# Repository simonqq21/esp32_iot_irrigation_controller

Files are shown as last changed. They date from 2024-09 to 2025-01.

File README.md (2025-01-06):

# ESP32 WiFi-Enabled Relay

# Introduction
The ESP32 WiFi-enabled relay is a proof-of-concept project that allows the user to control multiple AC sockets connected to relays by either a physical button, web interface on a browser, repeating daily schedule, countdown timer, or with other programming languages from a server computer via a websocket connection.  

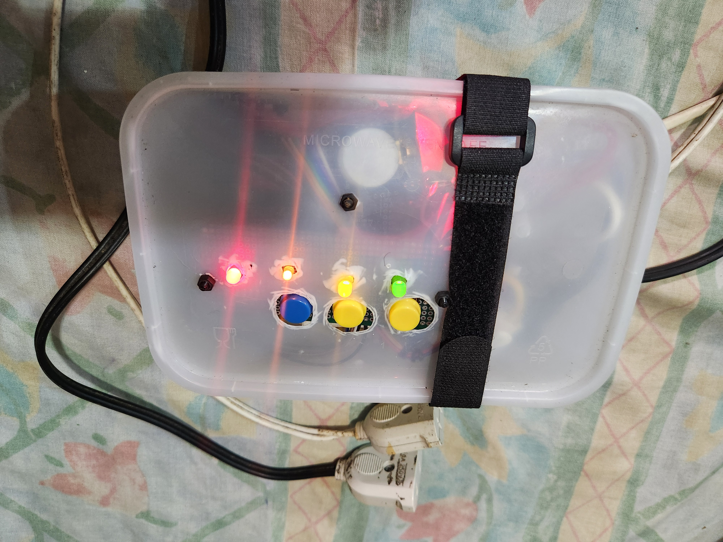
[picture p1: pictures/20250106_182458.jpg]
ESP32 WiFi-Enabled Relay picture 1

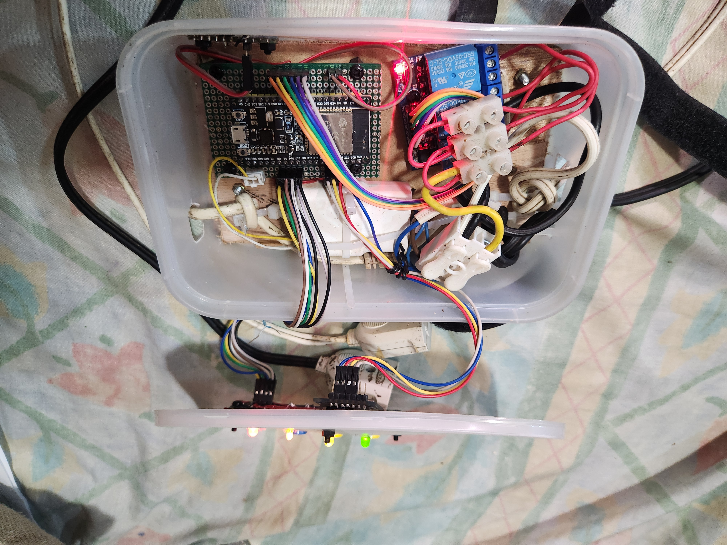
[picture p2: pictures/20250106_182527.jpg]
ESP32 WiFi-Enabled Relay picture 2

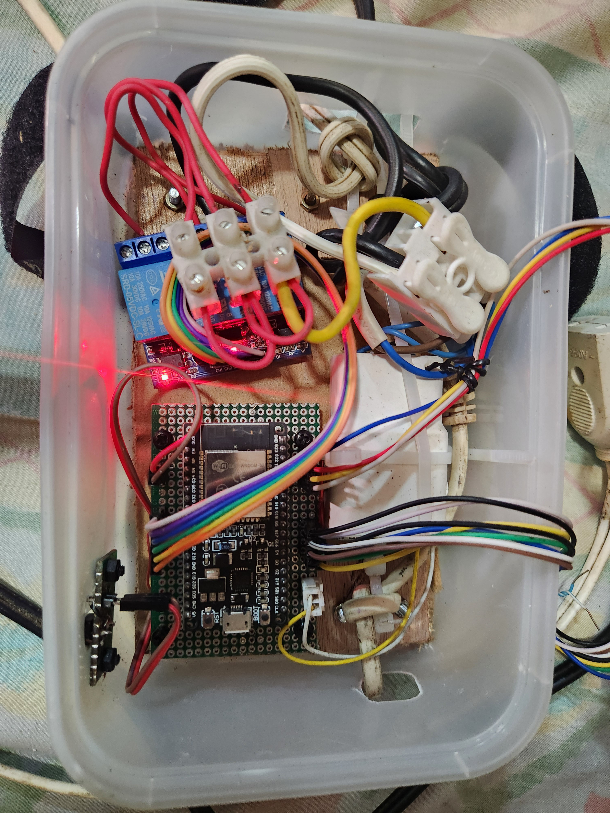
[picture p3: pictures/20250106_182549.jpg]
ESP32 WiFi-Enabled Relay picture 3


# Features
- Runs on an **ESP32**
- Three relays, but can be configured with more or less relays.
- Each relay functions independently of each other.
- Each relay has a **physical pushbutton** for **manual control** and **cycling through operating modes**, and a **status LED** to indicate its **operating mode** (either manual, daily timer, countdown timer, or disabled) and **current state** (either closed or open).
- The ESP32 can be **configured to connect to any WiFi hotspot** by configuring it from the browser of any mobile or desktop device, or **create its own hotspot** for standalone use.
- **Physical WiFi reset button** to reset the WiFi connection to factory defaults.
- **Web interface** accessible through the browser of any mobile or desktop device. 
- The web interface running on the browser communicates to the ESP32 via a **websocket connection**.
- Time is kept via a **real time clock (RTC)**, and can either be **set manually** or **synced automatically to network time protocol (NTP)**.
- All configuration is persistent and is saved to the flash of the ESP32. 

# Hardware 
## Hardware components
The ESP32 WiFi-enabled relay has the following hardware components:
- ESP32 
- 3.3V/5V relay module x3
- DS1307 RTC module
- LED x3 for relay status LEDs
- Momentary pushbutton x3 for relay control
- LED x1 for main status LED
- Momentary pushbutton x1 for WiFi reset pushbutton
- AC to 5V power supply module 
## Circuit Diagram
- **ESP32 PCB Circuit Diagram**

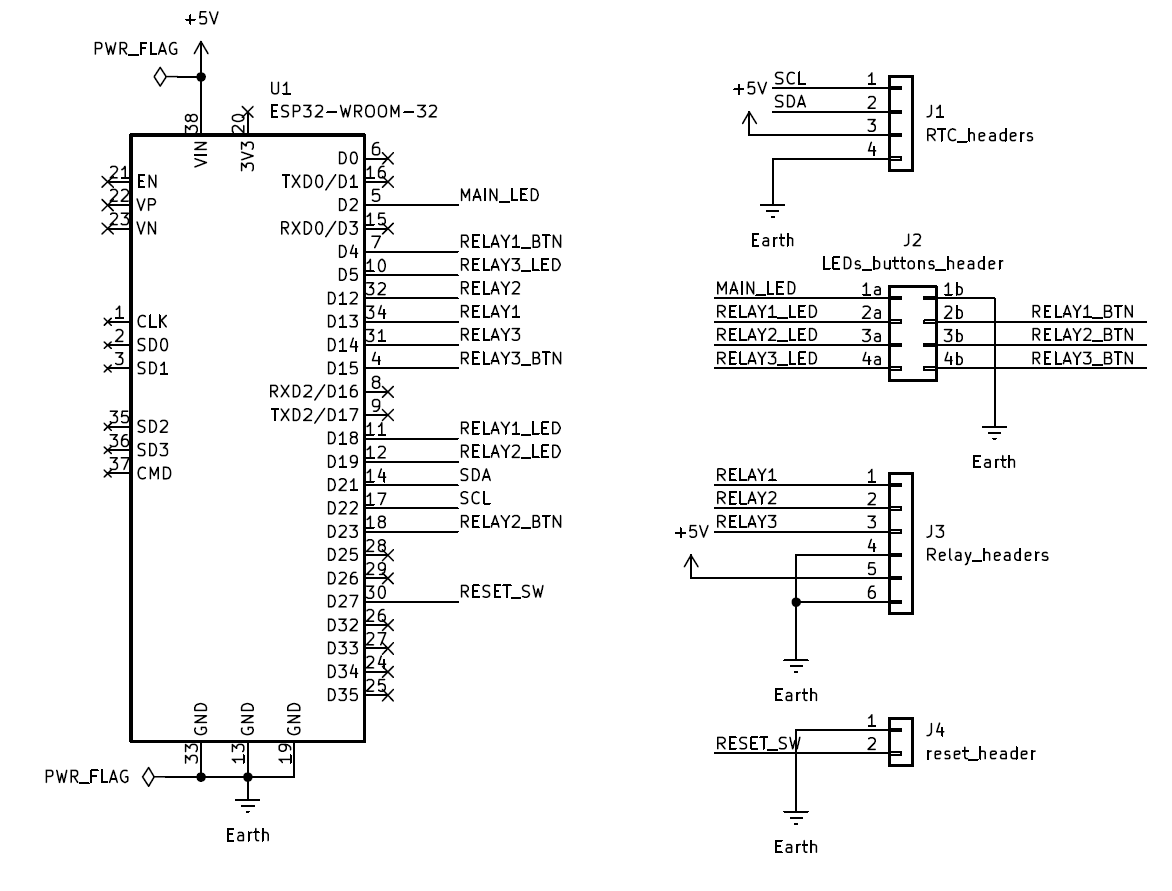
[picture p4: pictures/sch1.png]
ESP32 PCB Diagram


- **LEDs and Pushbuttons PCB Circuit Diagram**

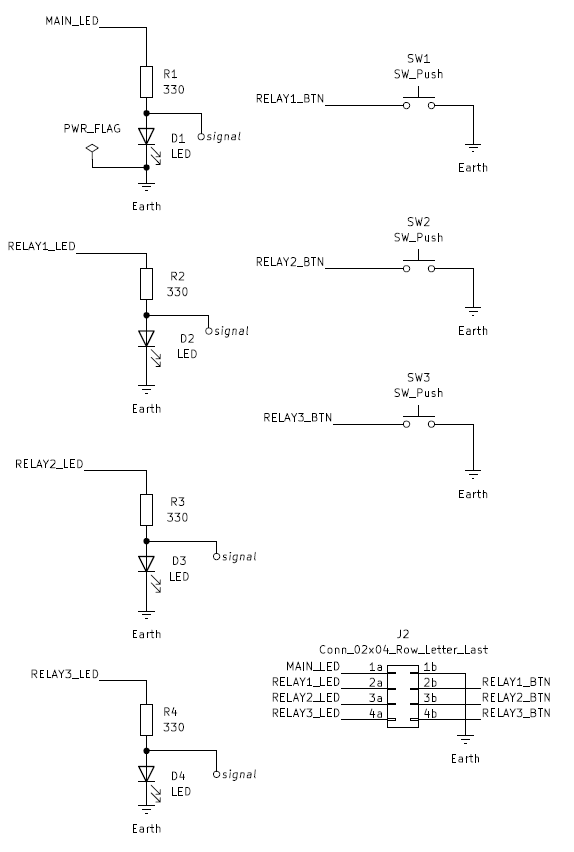
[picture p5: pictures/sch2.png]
LEDs and Pushbuttons PCB Diagram


- **WiFi Reset Pushbutton PCB Circuit Diagram**

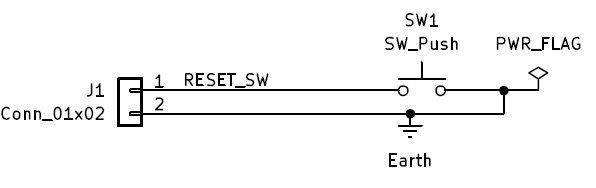
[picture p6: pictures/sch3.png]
WiFi Reset Pushbutton PCB Diagram


## PCB Design 

- **ESP32 PCB**

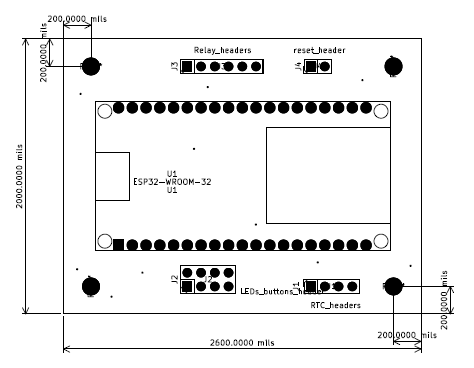
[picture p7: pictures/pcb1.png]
ESP32 PCB print

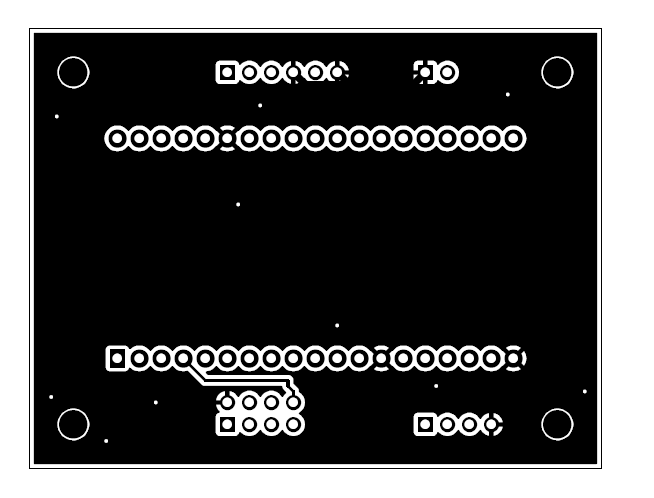
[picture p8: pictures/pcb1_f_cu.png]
ESP32 PCB front Cu

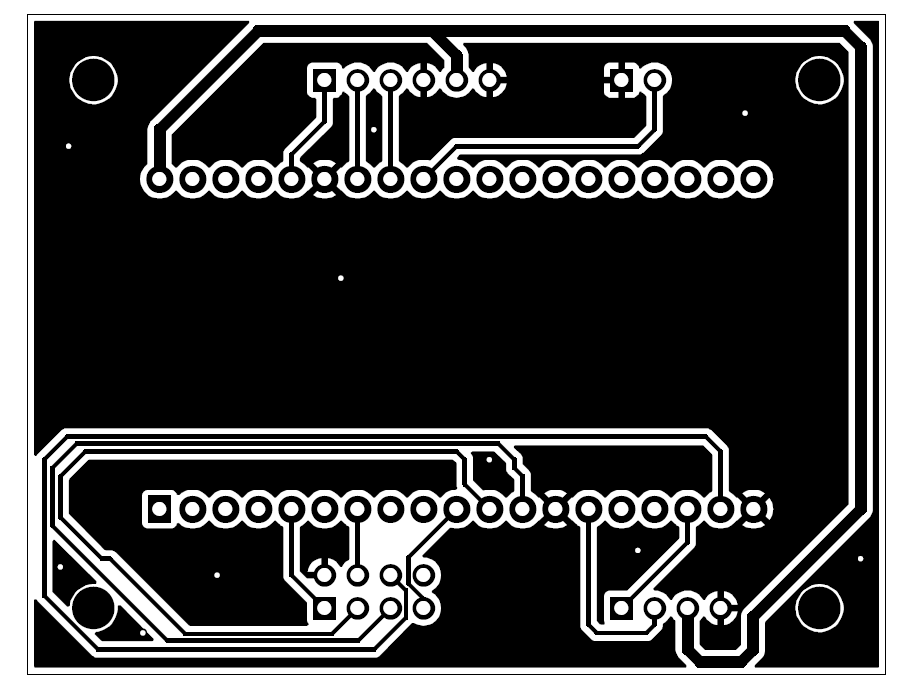
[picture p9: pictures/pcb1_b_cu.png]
ESP32 PCB back Cu


- **LEDs and Pushbuttons PCB**

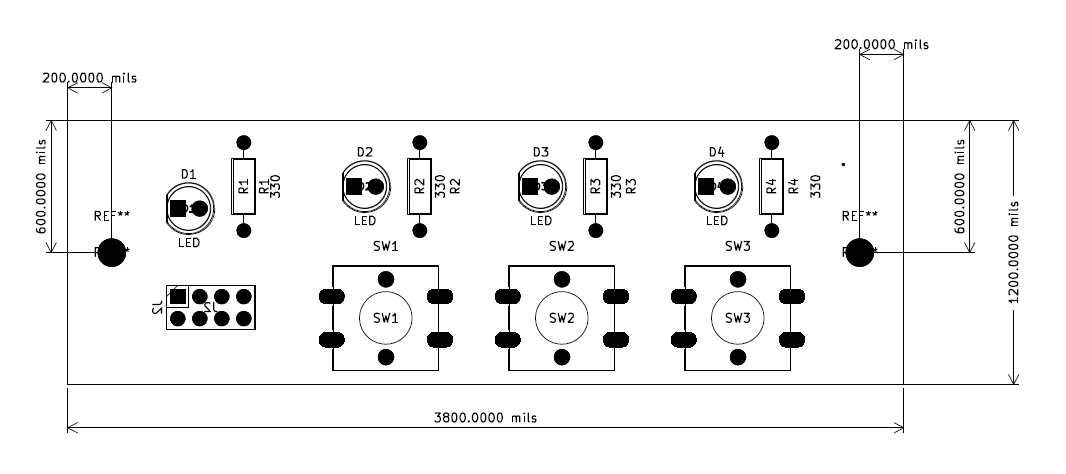
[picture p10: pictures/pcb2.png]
LEDs and Pushbuttons PCB print

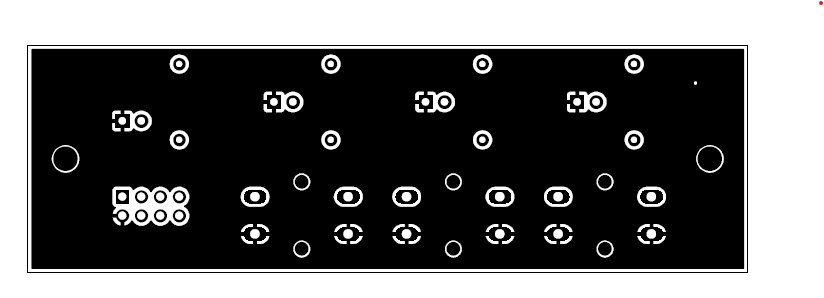
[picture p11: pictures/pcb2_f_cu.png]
LEDs and Pushbuttons PCB front Cu

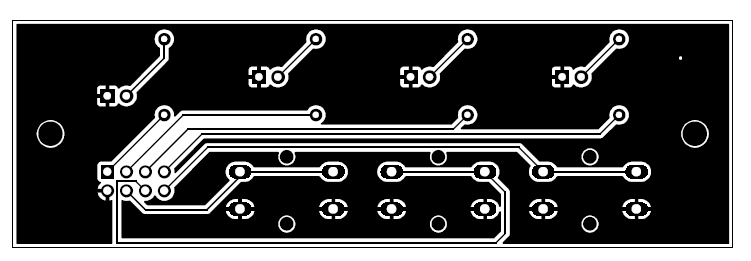
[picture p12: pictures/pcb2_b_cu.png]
LEDs and Pushbuttons PCB back Cu


- **WiFi Reset Pushbutton PCB**

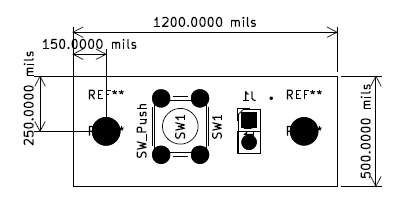
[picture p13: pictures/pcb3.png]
WiFi Reset Pushbutton PCB print

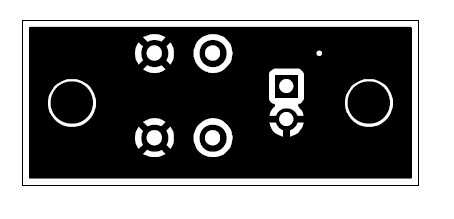
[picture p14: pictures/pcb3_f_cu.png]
WiFi Reset Pushbutton PCB front Cu

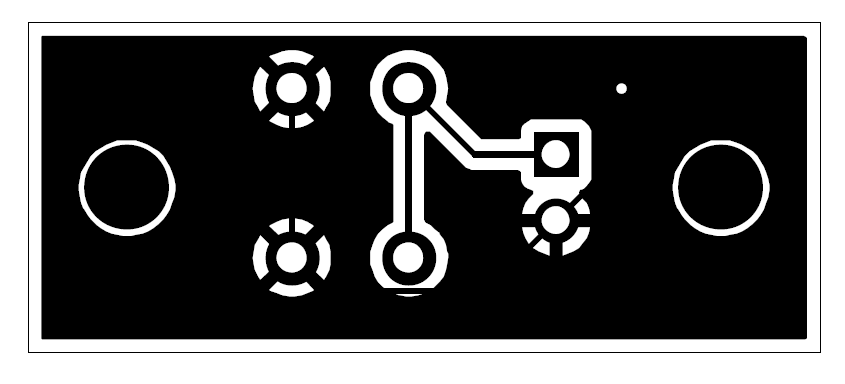
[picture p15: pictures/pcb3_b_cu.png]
WiFi Reset Pushbutton PCB back Cu


## Enclosure Design 
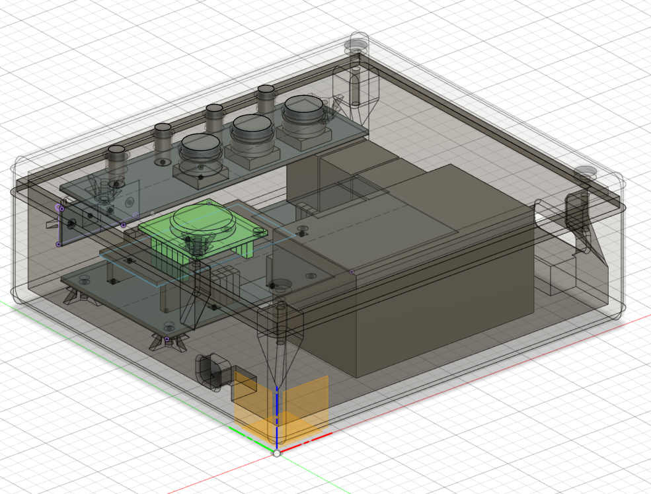
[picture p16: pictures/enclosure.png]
3D model of enclosure

# Installation
## Prerequisite software: 
- VS Code
- PlatformIO extension for VS Code 
## Installation Procedure 
1. Download and install **VS Code**. 
2. Download the **PlatformIO extension** within the VS Code extension manager. 
3. Clone this project from Github.
4. Open the cloned project folder in VS Code.
5. Open the **PlatformIO toolbar** from the VS Code sidebar. Your editor must look like this:

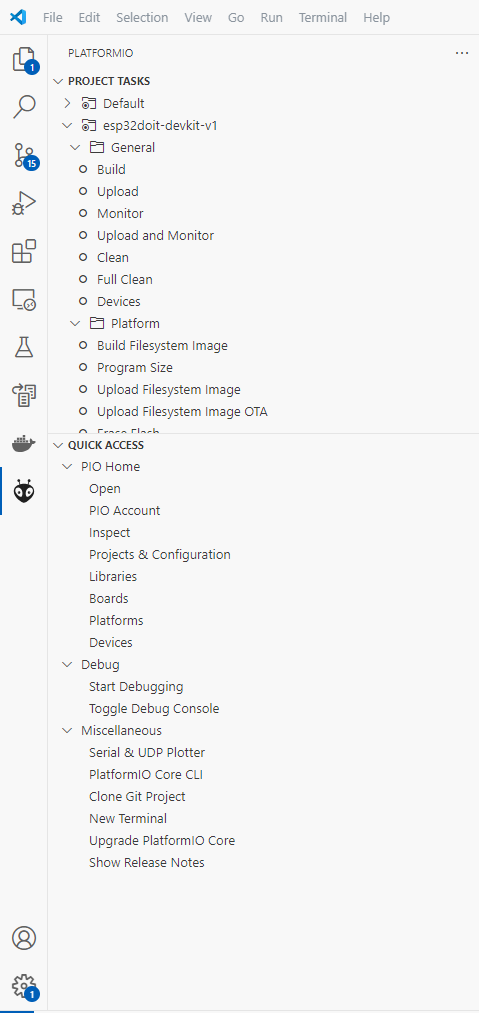
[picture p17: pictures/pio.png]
PlatformIO toolbar in VS Code


6. Upload the program to the ESP32. Click on the **esp32doit-devkit-v1/General/Upload** option inside the PlatformIO toolbar. It might take a few minutes as PlatformIO downloads all the dependencies for the project.

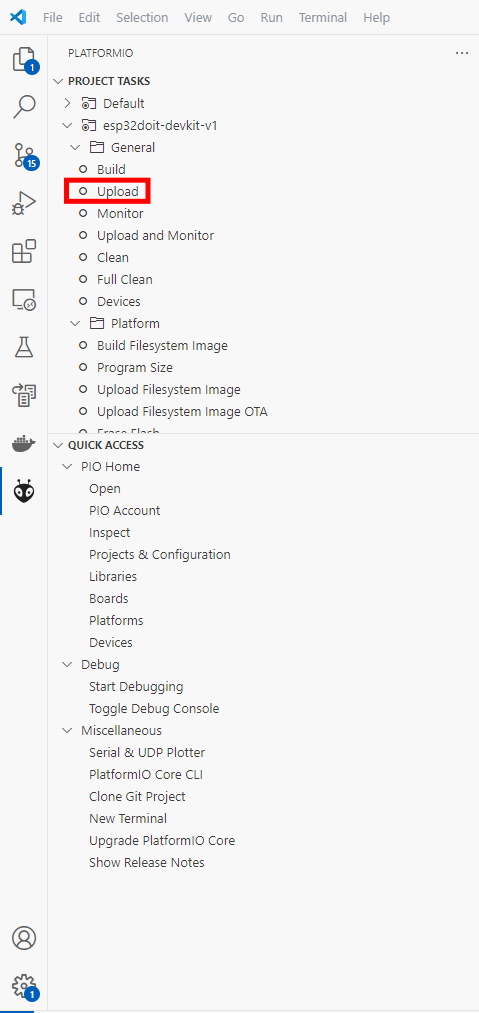
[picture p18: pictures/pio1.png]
Upload esp32 program


7. Upload the filesystem image to the ESP32. Click on the **esp32doit-devkit-v1/Platform/Upload filesystem image** option inside the PlatformIO toolbar.

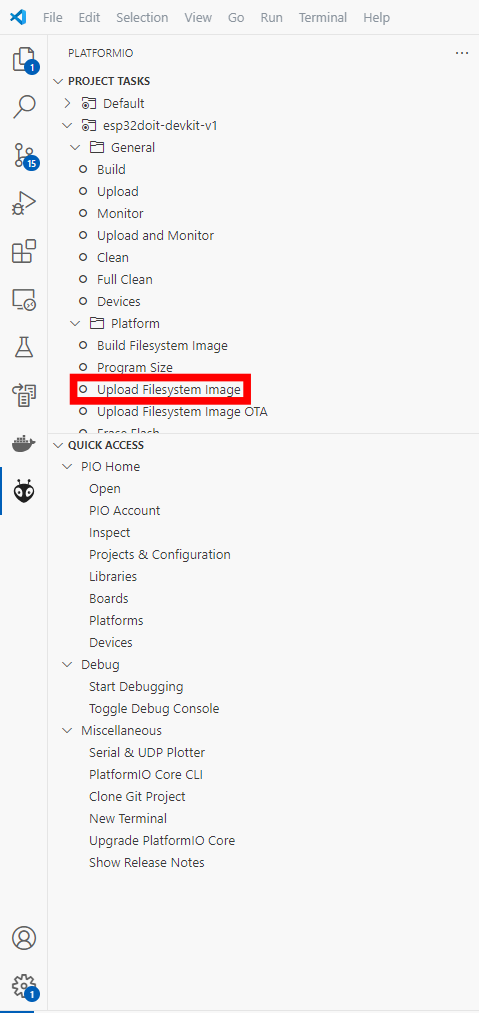
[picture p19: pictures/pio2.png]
Upload esp32 filesystem image


Installation complete. 

# Usage
## Relay Operating Modes
- **Manual mode** retains the state of the relay until the user changes it either on the web interface or the physical pushbutton.
- **Daily timer mode** allows the user to set multiple timeslots. Each timeslot has a start and end time which has a maximum duration of one day, and can be enabled or disabled. By default, the relay is open. When the current time falls within at least one enabled timeslot, the relay will be closed. 
- **Countdown timer** allows the user to set a countdown duration and manually start and stop the countdown timer. When the countdown timer is started, the relay will close until either the countdown timer reaches zero or is manually stopped, then the relay will remain open until the user restarts the countdown timer. The countdown duration is saved.
- **Disabled** - the relay is always open.
## Relay Pushbutton
Each relay has a **physical pushbutton** for **manual control** and **cycling through operating modes**
- **Single click**
    - In manual mode, a single click toggles the relay state.
    - In countdown timer mode, a single click (re)starts and stops the countdown timer.
    - No effect in all other modes. 
- **Double click** 
    - In any mode, double click cycles through all modes (manual mode - daily timer mode - countdown timer mode - disabled).
## Relay Status LED 
Each relay has a **status LED** to indicate its **operating mode** (either manual, daily timer, countdown timer, or disabled) and **current state** (either relay closed or relay open).
- **Current operation mode**
    - The relay LED blinks a number of times to indicate the current operation mode. It blinks once if the relay is in manual mode, twice if the relay is in daily timer mode, thrice if the relay is in countdown timer mode, and none if the relay is disabled.
- **Current relay state**
    - After indicating the current operation mode, the LED will turn on if the relay is currently closed, and turn off if the relay is currently open. 
## Configuring the WiFi connection
The ESP32 WiFi-Enabled relay can either produce its own WiFi hotspot in **station mode**, or connect to a WiFi hotspot in **access point mode**.
- Upon startup, the ESP32 will attempt to connect to the stored WiFi SSID (and password, if the WiFi is password secured). If it does not connect successfully for any reason, such as a nonexistent SSID or an incorrect password, it will automatically switch to access point mode and start its WiFi hotspot, which is an open WiFi network so that the user can connect to it to either use as-is, or to configure it to connect to their desired WiFi network.
- When the ESP32 is in access point mode, the ESP32 is accessible by connecting to the open WiFi network with SSID **ESP32_wifi_manager** and entering *http://192.168.4.1:7777/wifi.html* into the URL bar of the web browser. This opens up the ESP32 WiFi manager page. 

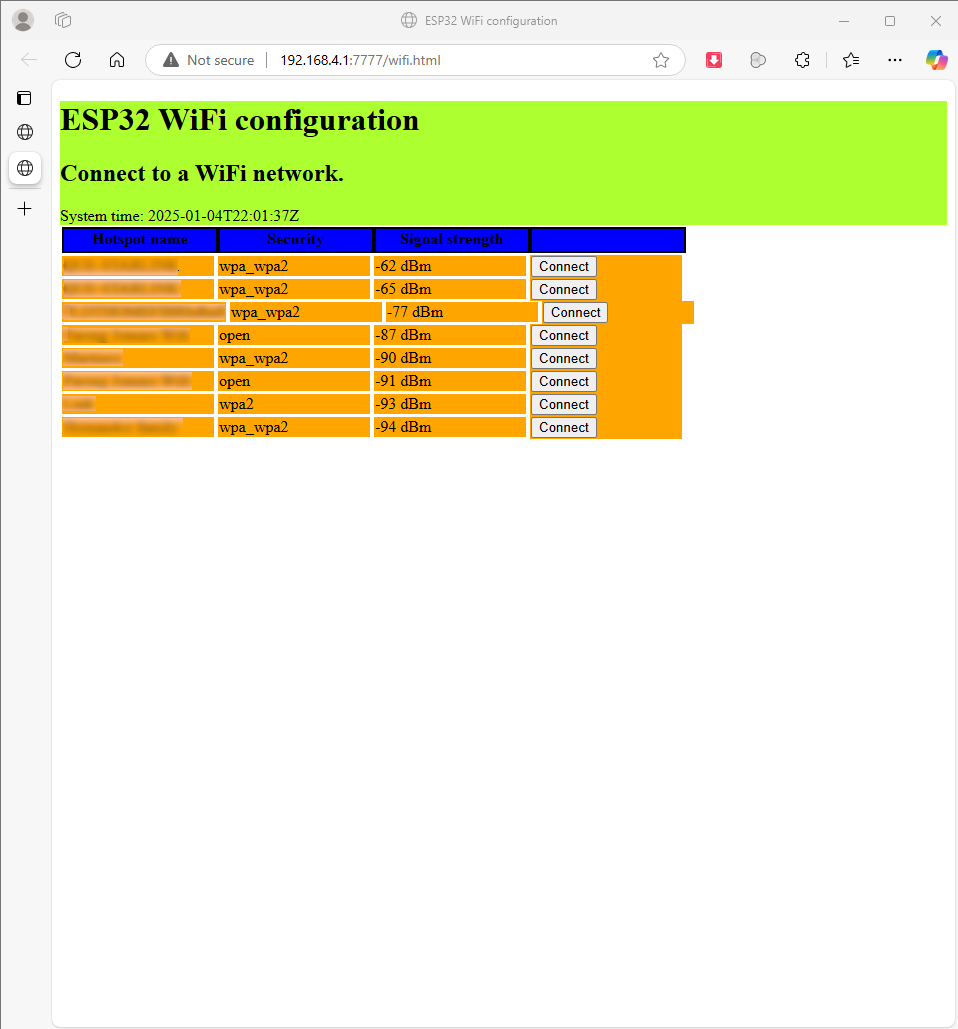
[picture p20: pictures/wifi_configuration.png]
ESP32 WiFi manager page


- Clicking the **Connect** button will direct the browser into the WiFi connect menu. Here, the user enters a WiFi password (if the WiFi is password secured) and the desired last octet of the IP address which ranges from 0-255. The last octet is used to set the *static IP address* of the ESP32 in the WiFi network it connects to so that it will be straightfoward to find and address the ESP32 in the network. The port number input is ignored because the port has been hardcoded to *7777*.

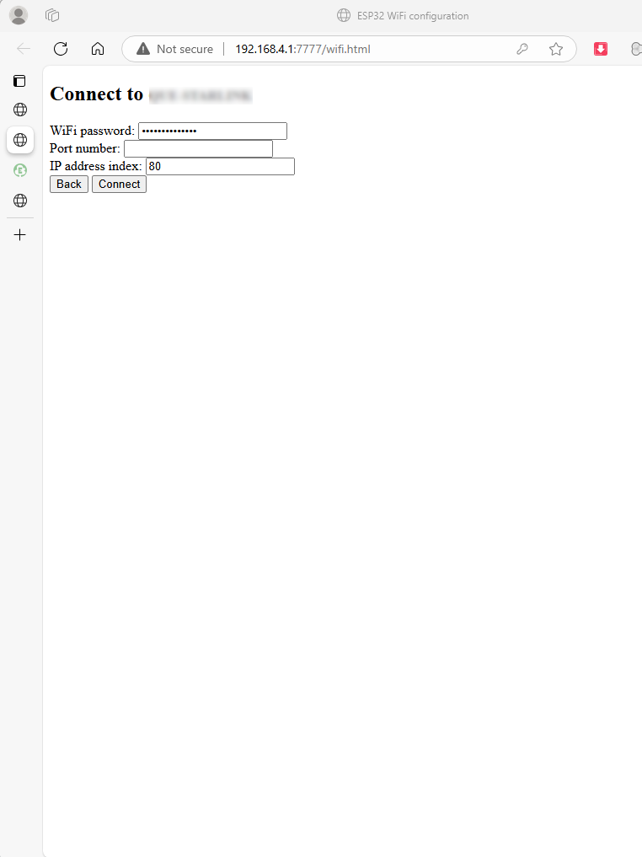
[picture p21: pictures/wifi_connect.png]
ESP32 connect to WiFi page


- A **reset pushbutton** allows the user to manually reset the WiFi credentials stored on the ESP32 even without having network access to the ESP32 so that the ESP32 will be reset into access point mode and the user can reconfigure the WiFi connection. **Long-pressing** the WiFi reset pushbutton until the main status LED blinks three times resets the WiFi credentials and restarts the ESP32. 

## Web Interface
The **web interface** allows the user to change various settings, including but not limited to the device name, relay operating modes, and relay state.
- **If the ESP32 is connected to a WiFi hotspot**, the web interface is accessible through the link *http://router_IP_subnet.ESP32_IP_index:7777/*. For example, if your WiFi router's network range is 192.168.5.0 to 192.168.5.255 and you set the ESP32 to have an IP address index of 80, then the URL to access the web interface is *http://192.168.5.80:7777/*.
- **If the ESP32 is in access point mode**, then its IP address is hardcoded  to *192.168.4.1*, so the URL to access the web interface is *http://192.168.4.1:7777/*. 
- The web interface allows the user to change the following configuration:
    - ESP32 device name
    - System date and time
    - Automatically sync time or set time manually 
    - main status LED setting
    - Relay status LED setting
    - Relay operation mode
    - Relay state (in manual mode)
    - Relay timeslots (in daily timer mode)
    - Relay countdown timer duration (in countdown timer mode)
- The web interface also displays status and information.
    - System date and time
    - Relay status
    - All settings
- The web interface communicates to the ESP32 via a **websocket connection**. This allows multiple ESP32 units on the same WiFi network to be programmatically controlled with the websocket libraries of various programming languages such as Python. The formats of the websocket messages are specified in *lib/Websocket_module/Webserver_module.h*.

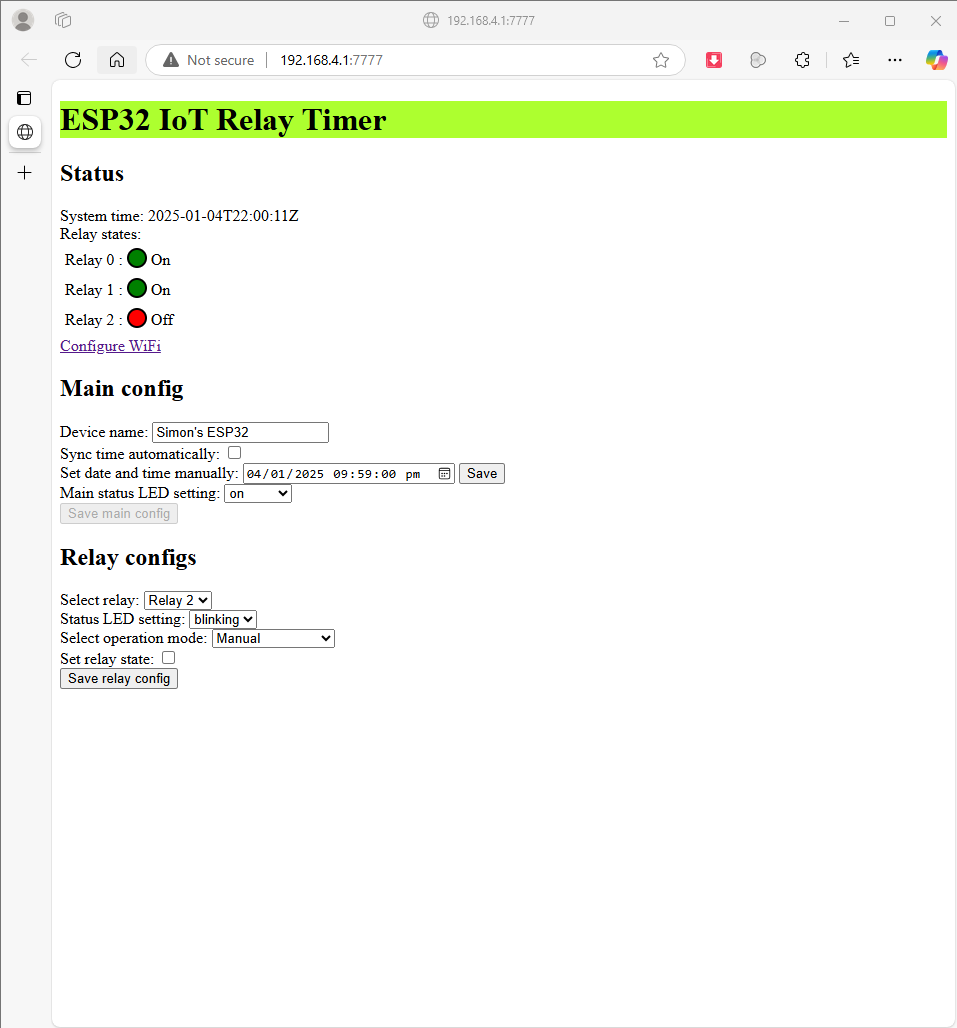
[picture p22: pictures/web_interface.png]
Web interface


- Change the selected relay to view and manage its settings.

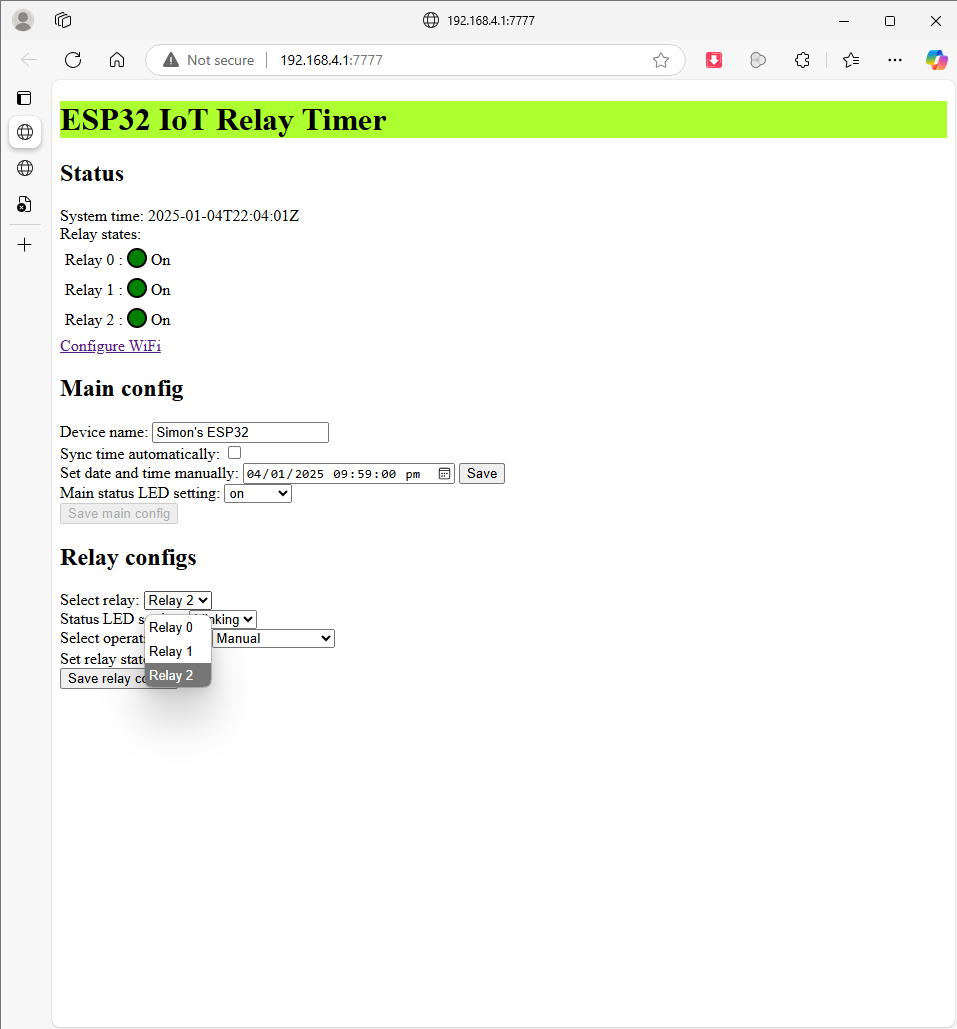
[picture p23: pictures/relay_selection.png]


- Change the operation mode of the selected relay.

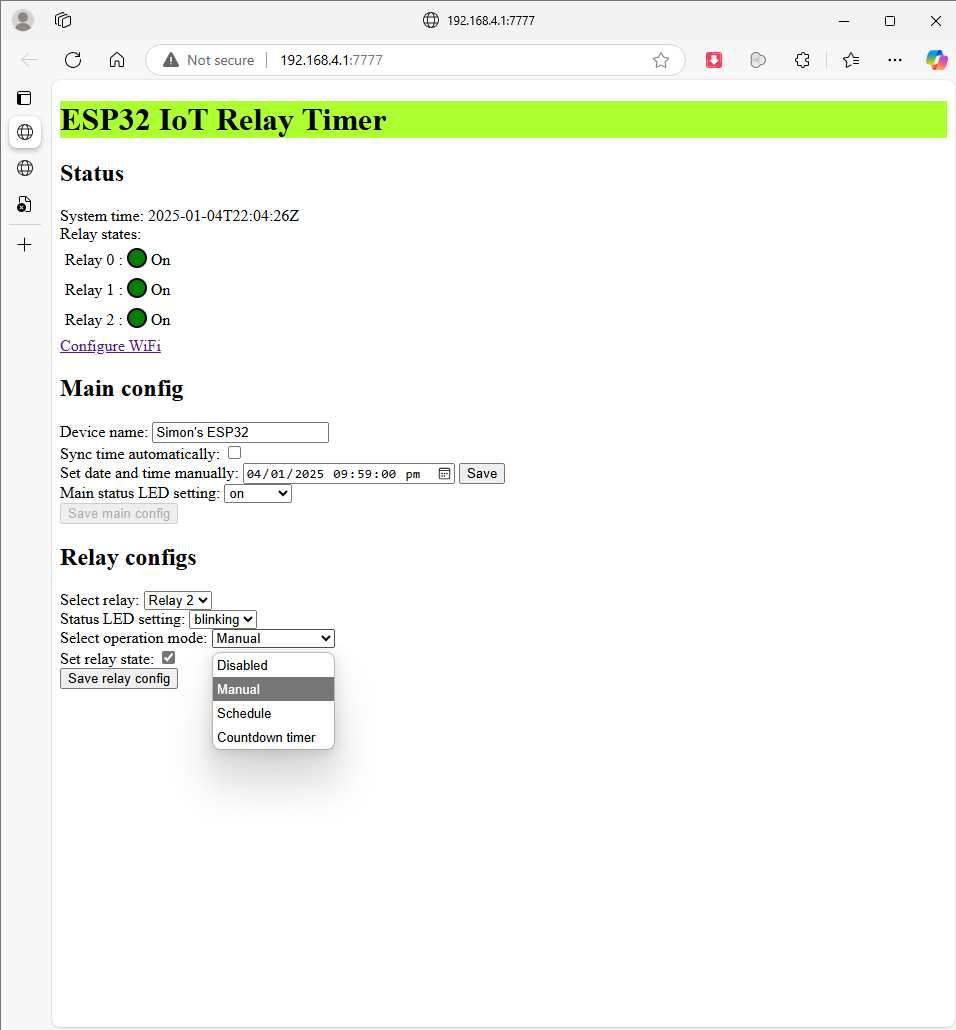
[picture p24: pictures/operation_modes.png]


- When a relay is in **manual mode**, the relay state can be changed.

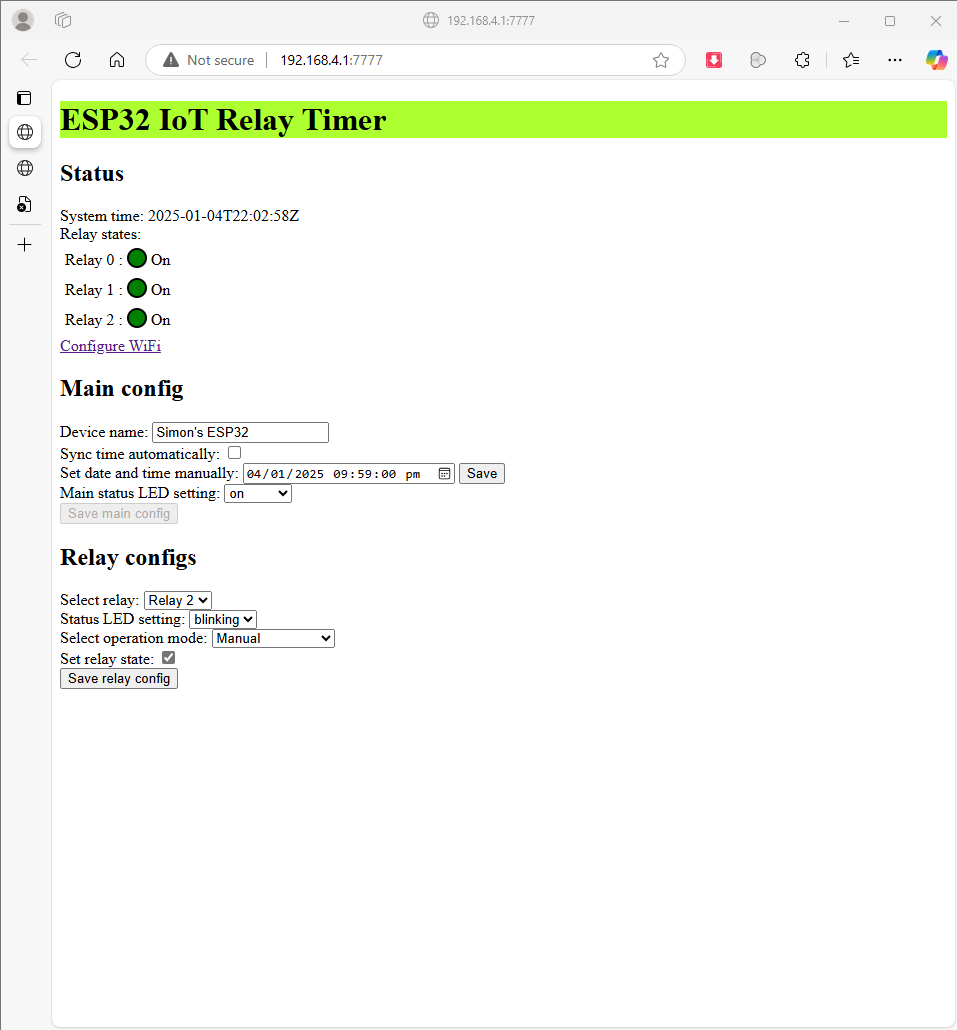
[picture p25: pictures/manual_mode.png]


- When a relay is in **daily timer mode**, the start time, end time, duration, and enabled setting of each timeslot can be changed.

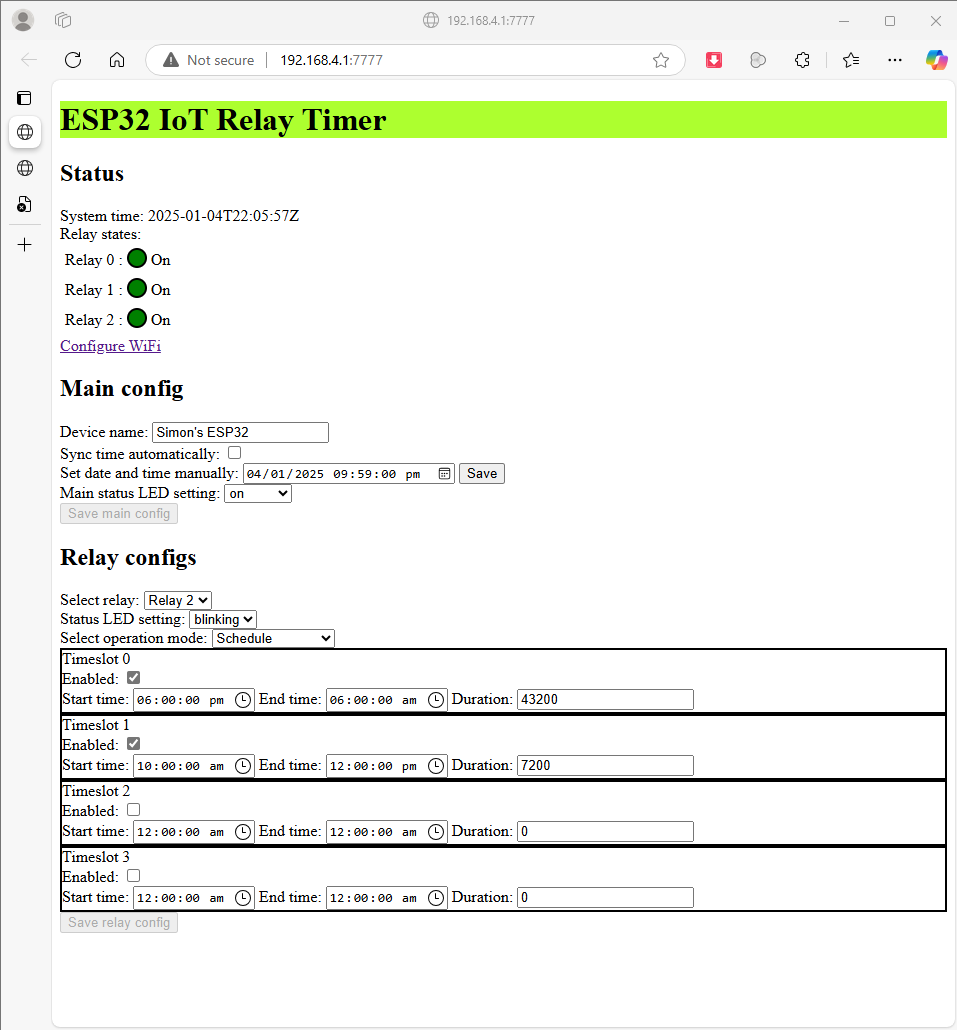
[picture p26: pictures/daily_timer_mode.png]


- When a relay is in **countdown timer mode**, the countdown timer duration in seconds can be changed and the countdown timer can be started and stopped.

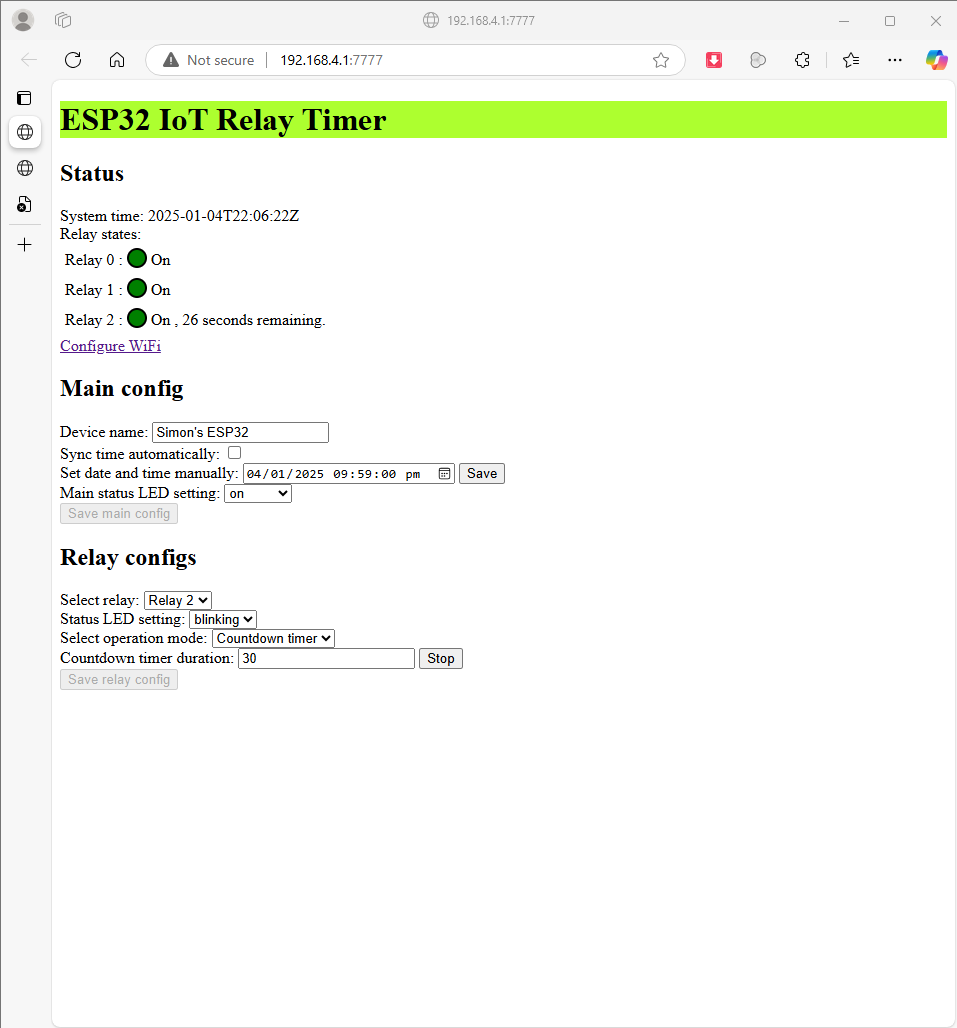
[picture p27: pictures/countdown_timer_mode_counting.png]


- There are countdown timers in the relay status indicators that indicate how much time the relay countdown timer has left before the relay opens.

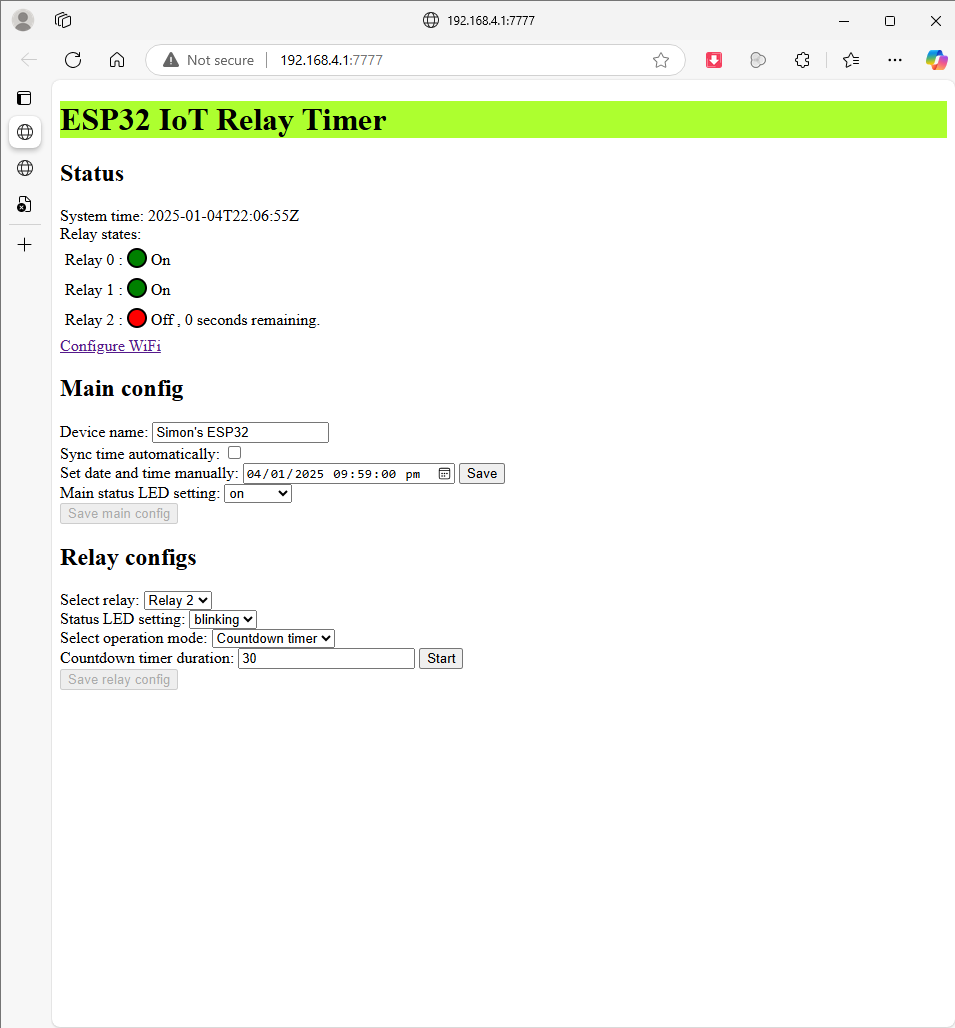
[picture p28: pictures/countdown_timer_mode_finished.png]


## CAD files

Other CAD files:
esp32_iot_relay_enclosure v102.f3d

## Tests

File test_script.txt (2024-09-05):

short press button when timer is disabled must toggle relay
double press button toggles timer enable/disable.
long press button resets the wifi connection and enables AP mode.

datetime is loaded properly upon startup
when NTP is enabled, datetime is up to date.
Changing GMT offset when NTP is enabled also changes the system time. 
changing the manual relay state when the timer is disabled changes the relay.
changing status LED setting changes the LED behavior instantly.

changing timerEnabled to true when there is a timeslot that is enabled now must turn on
    the relay.
Changing a timeslot with the time now to enabled when timerEnabled is true must turn on 
    the relay.
Changing a timeslot with the time now to disabled when timerEnabled is true must turn off 
    the relay.
Changing timerEnabled to false must set the relay to the mode set in manual mode.

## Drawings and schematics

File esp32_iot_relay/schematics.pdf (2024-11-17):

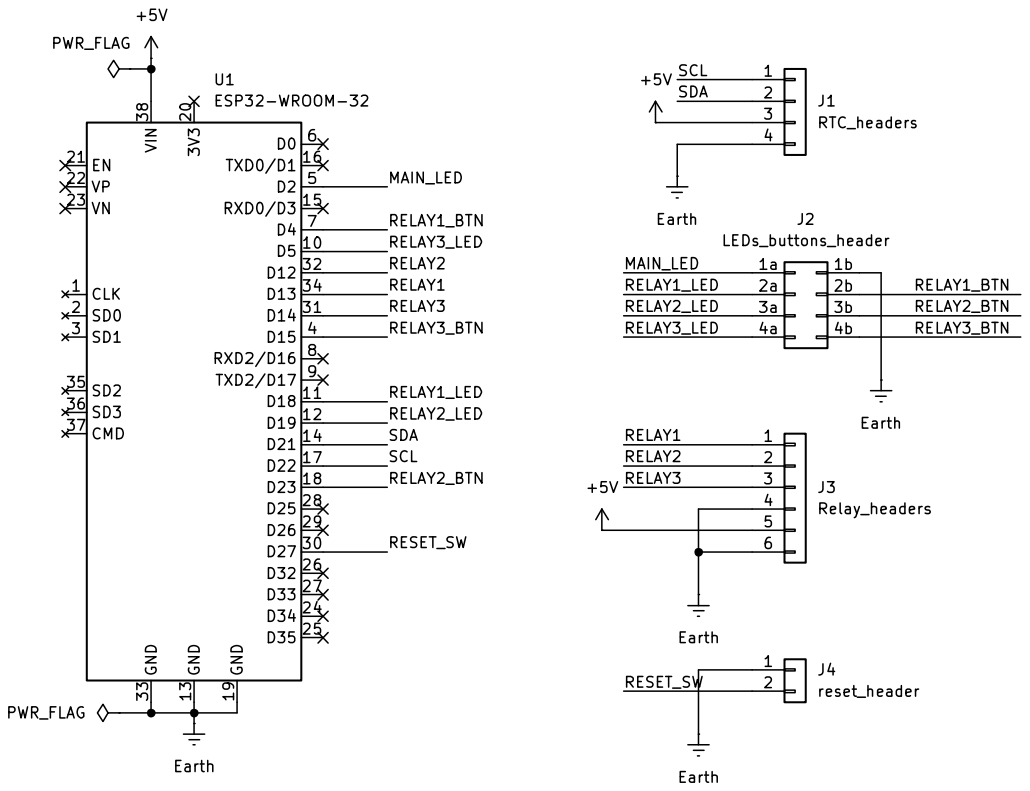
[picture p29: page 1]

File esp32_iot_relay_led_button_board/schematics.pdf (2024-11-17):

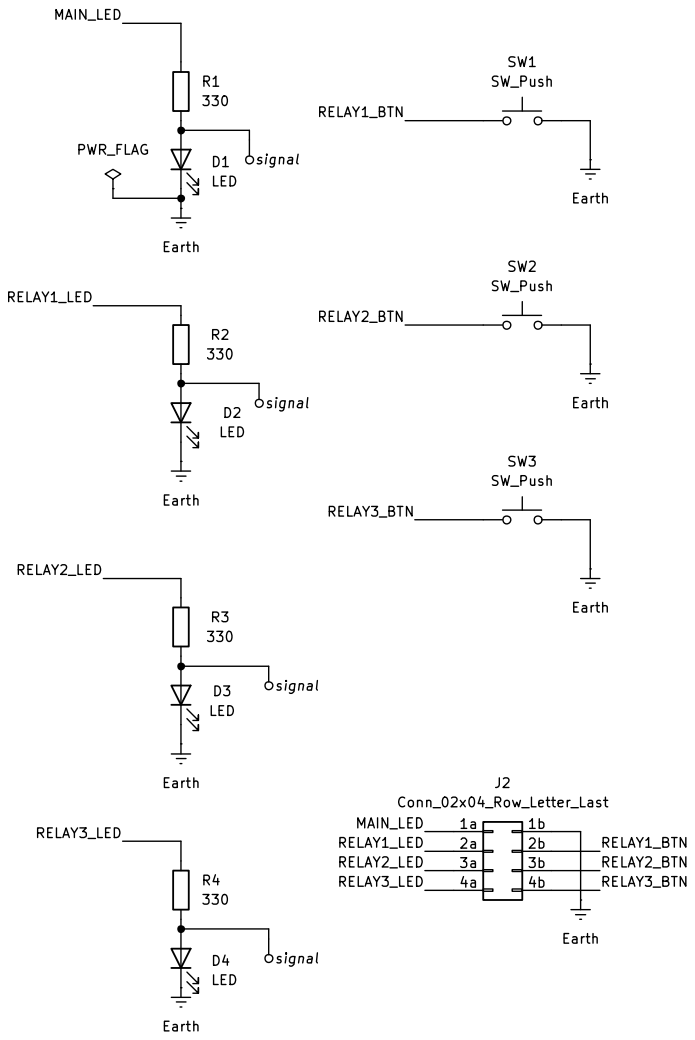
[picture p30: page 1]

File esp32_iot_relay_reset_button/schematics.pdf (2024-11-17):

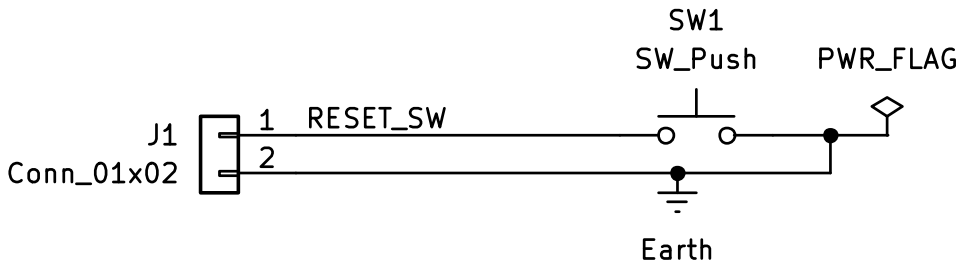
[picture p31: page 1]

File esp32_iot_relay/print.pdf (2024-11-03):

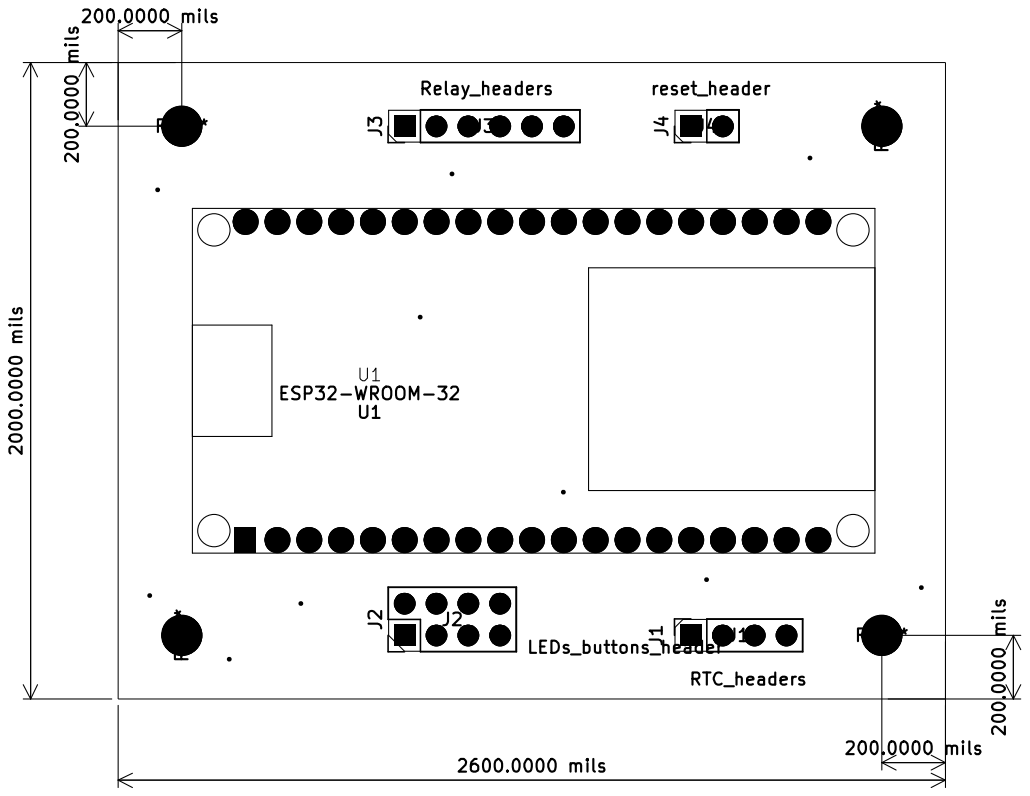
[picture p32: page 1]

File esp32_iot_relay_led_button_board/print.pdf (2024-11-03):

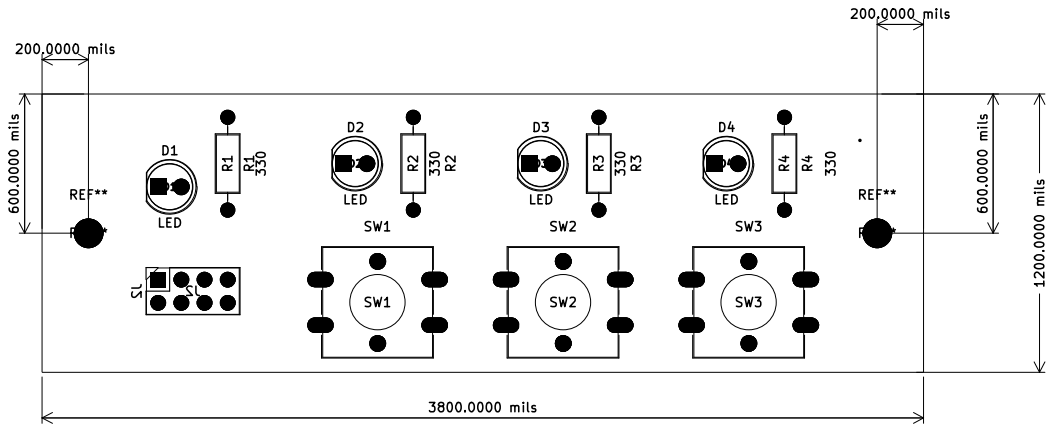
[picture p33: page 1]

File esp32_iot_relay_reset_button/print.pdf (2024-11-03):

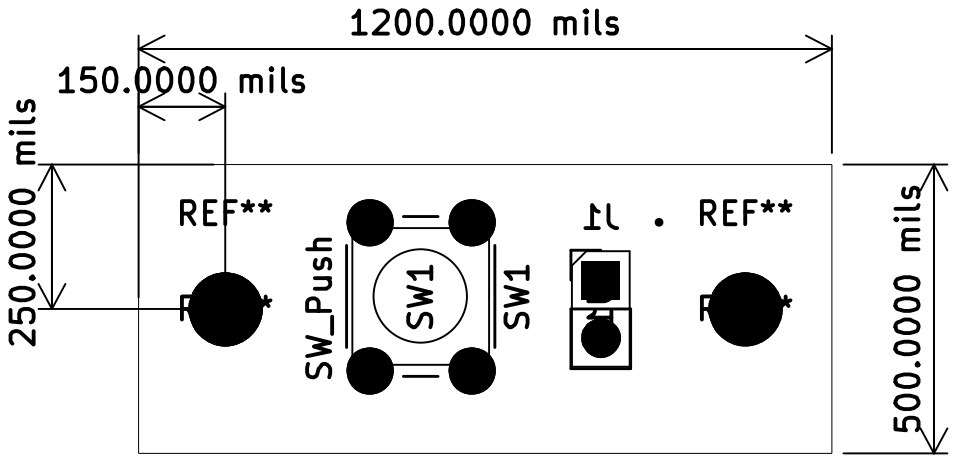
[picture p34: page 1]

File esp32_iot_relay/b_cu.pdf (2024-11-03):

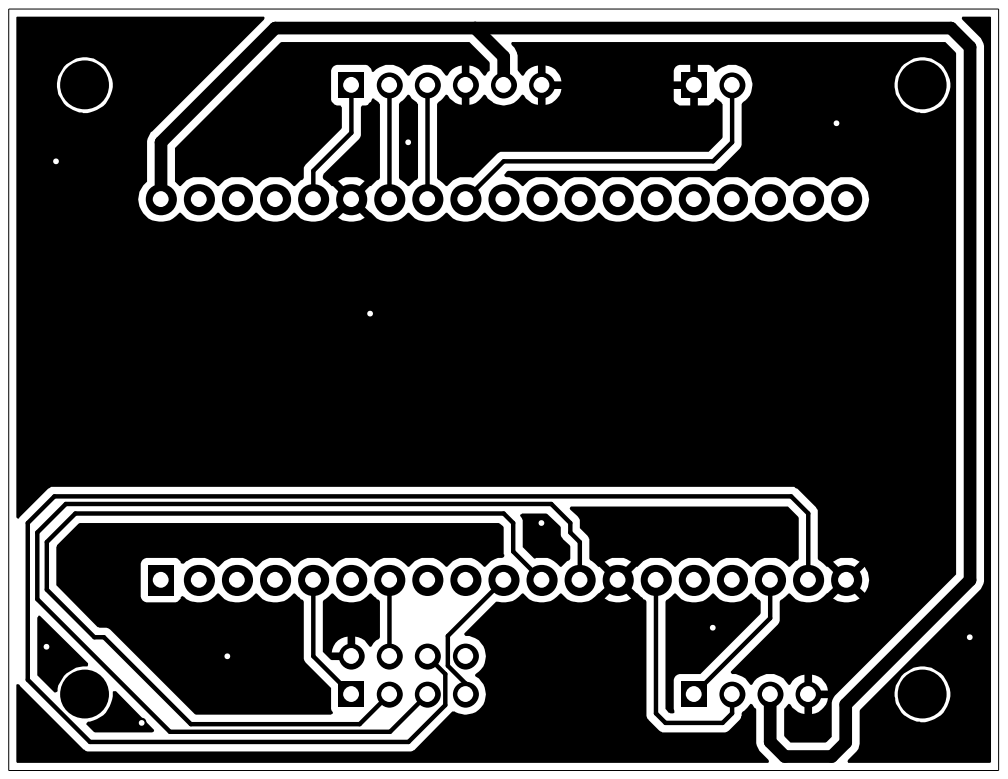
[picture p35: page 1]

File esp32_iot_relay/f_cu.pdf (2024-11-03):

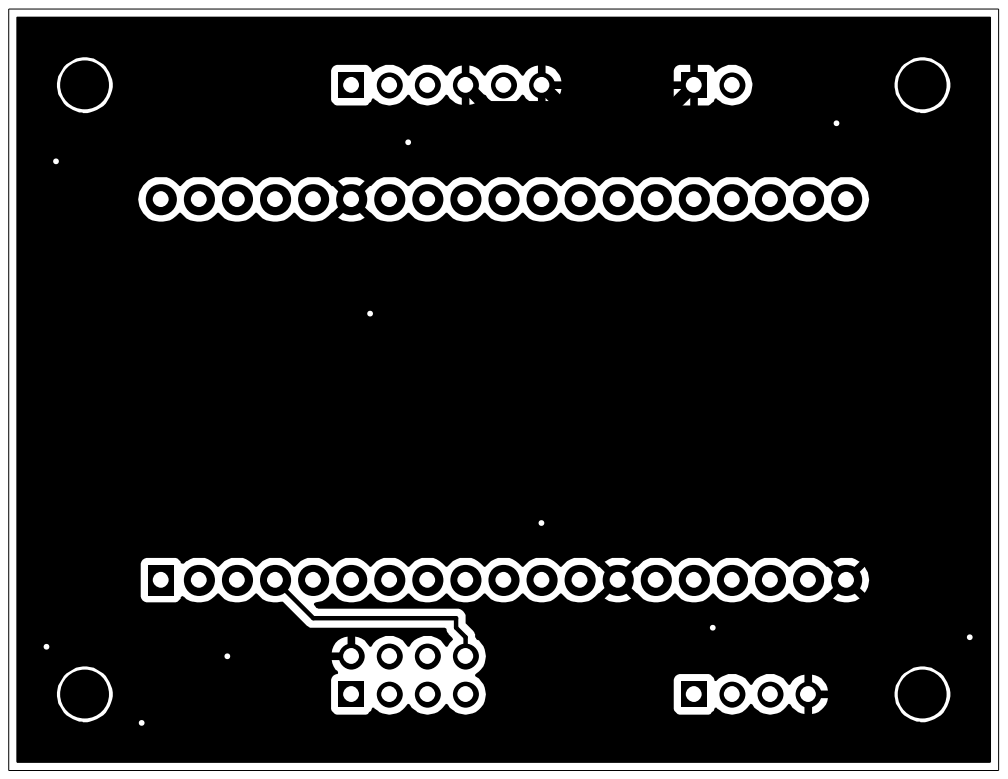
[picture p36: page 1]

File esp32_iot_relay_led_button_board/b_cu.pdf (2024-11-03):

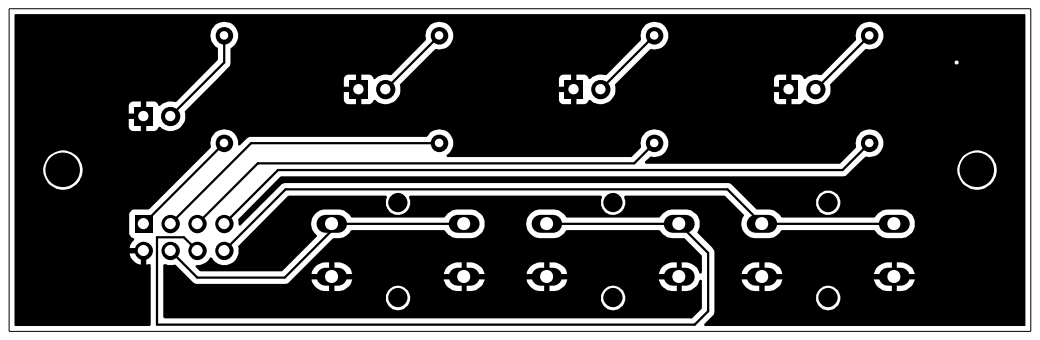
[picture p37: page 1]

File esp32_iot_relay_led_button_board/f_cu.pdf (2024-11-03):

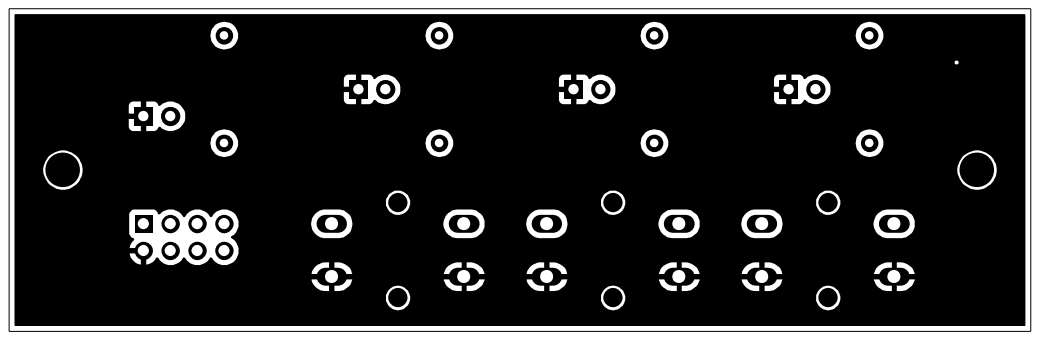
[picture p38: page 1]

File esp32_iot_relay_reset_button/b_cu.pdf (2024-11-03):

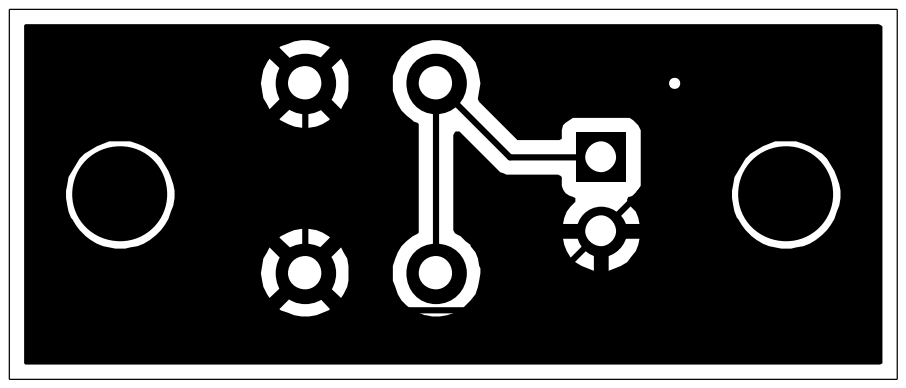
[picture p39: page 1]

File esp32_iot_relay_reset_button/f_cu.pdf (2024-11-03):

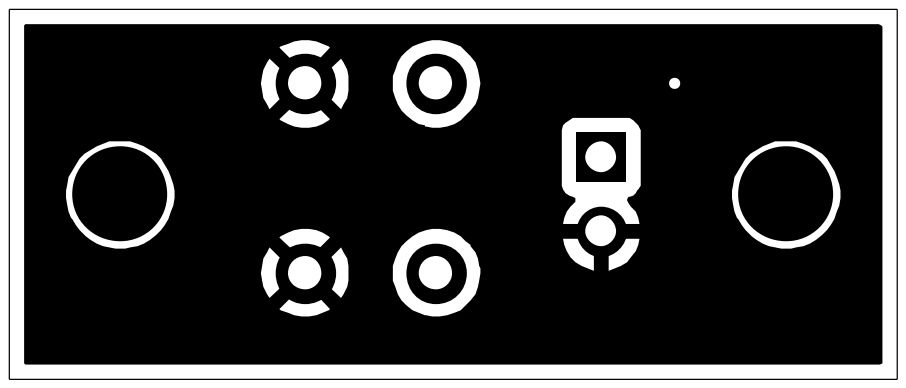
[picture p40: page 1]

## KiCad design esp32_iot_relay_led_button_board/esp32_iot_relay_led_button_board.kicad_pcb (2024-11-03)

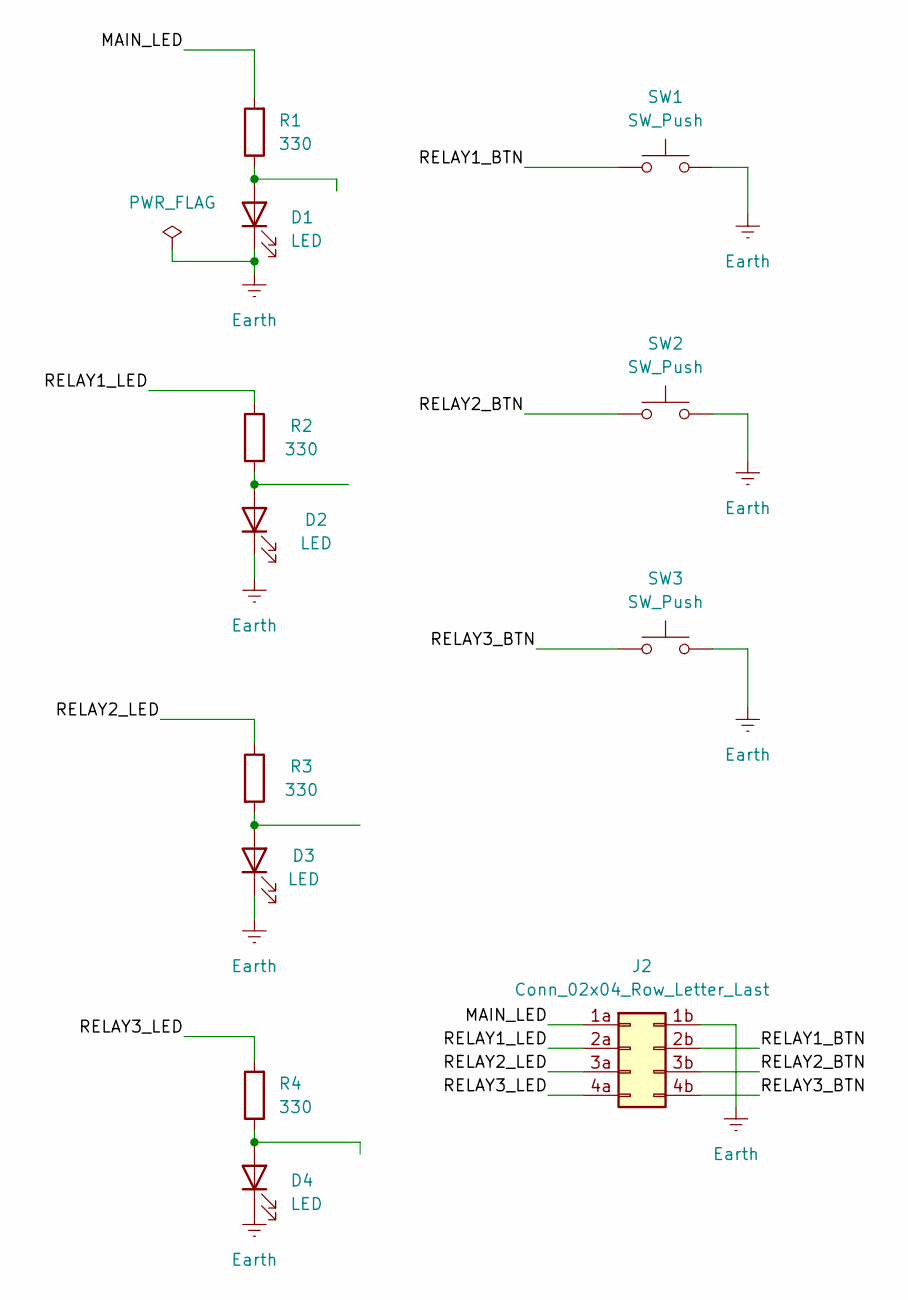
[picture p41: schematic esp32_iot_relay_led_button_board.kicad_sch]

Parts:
D1, D2, D3, D4: LED; LED_D5.0mm
J2: Conn_02x04_Row_Letter_Last; PinHeader_2x04_P2.54mm_Vertical_alphabetical
R1, R2, R3, R4: 330; R_Axial_DIN0207_L6.3mm_D2.5mm_P10.16mm_Horizontal
SW1, SW2, SW3: SW_Push; SW_SPST_Omron_B3F-40xx

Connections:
/MAIN_LED: J2.1a, R1.2
/RELAY1_BTN: J2.2b, SW1.1
/RELAY1_LED: J2.2a, R2.1
/RELAY2_BTN: J2.3b, SW2.1
/RELAY2_LED: J2.3a, R3.1
/RELAY3_BTN: J2.4b, SW3.1
/RELAY3_LED: J2.4a, R4.2
Earth: D1.1 (K), D2.1 (K), D3.1 (K), D4.1 (K), J2.1b, SW1.2, SW2.2, SW3.2
unnamed: D1.2 (A), R1.1
unnamed: D2.2 (A), R2.2
unnamed: D3.2 (A), R3.2
unnamed: D4.2 (A), R4.1

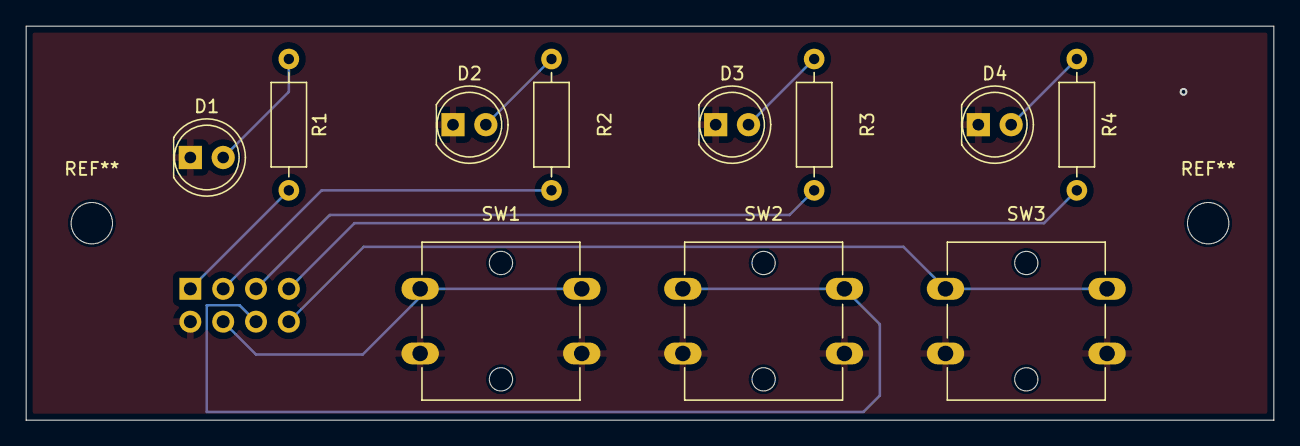
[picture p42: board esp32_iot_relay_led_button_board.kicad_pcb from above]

Board: 2 copper layers, 96.5 x 30.5 mm, 12 parts (1 on the bottom side), 12 nets.

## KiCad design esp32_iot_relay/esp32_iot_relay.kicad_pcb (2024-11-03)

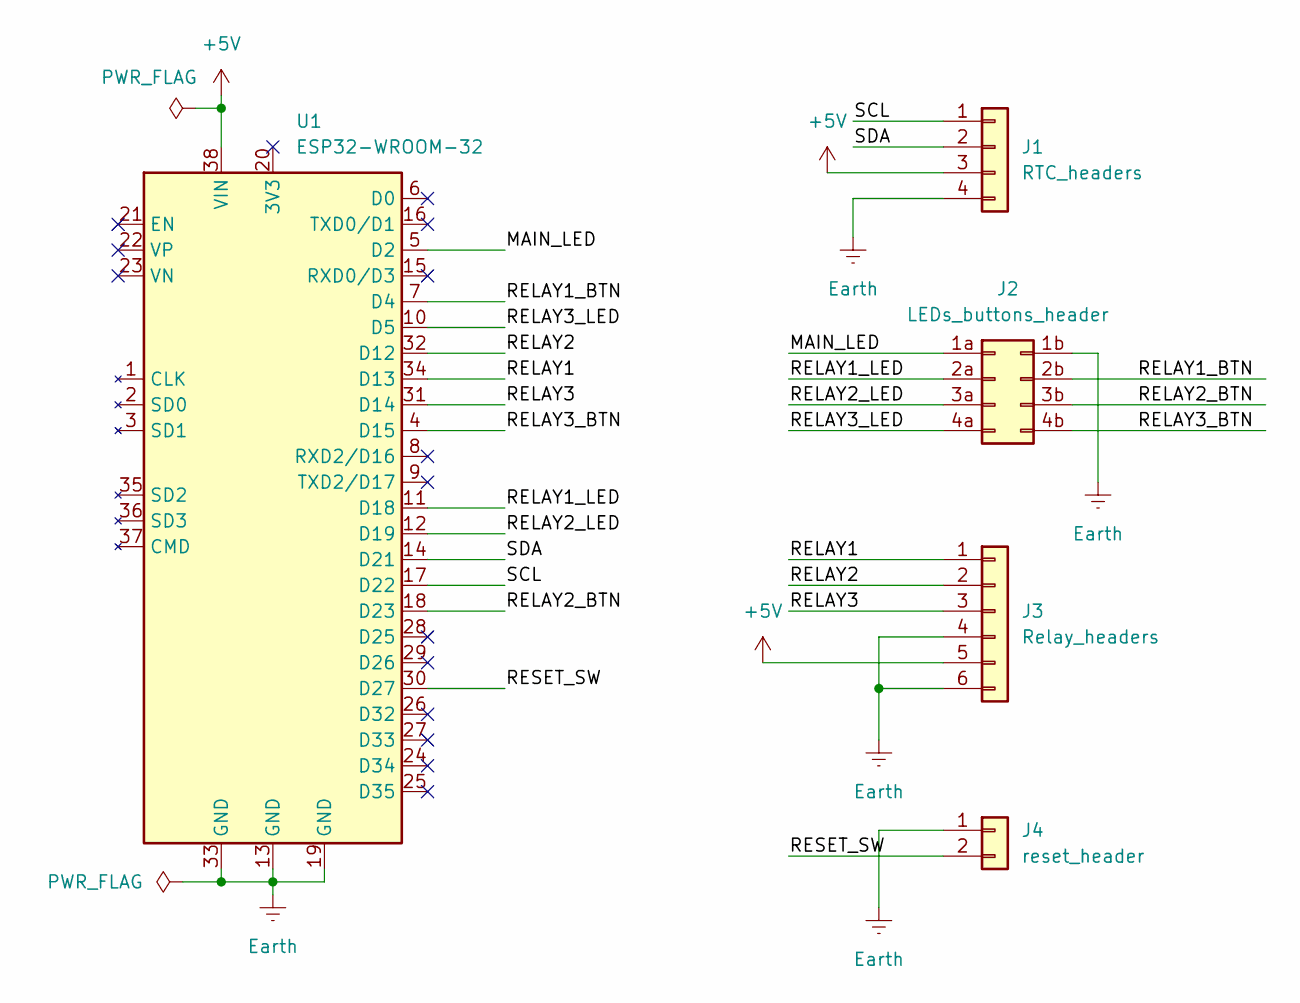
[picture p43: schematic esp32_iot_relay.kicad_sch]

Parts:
J1: RTC_headers; PinSocket_1x04_P2.54mm_Vertical
J2: LEDs_buttons_header; PinHeader_2x04_P2.54mm_Vertical_alphabetical
J3: Relay_headers; PinHeader_1x06_P2.54mm_Vertical
J4: reset_header; PinHeader_1x02_P2.54mm_Vertical
U1: ESP32-WROOM-32; esp32_doit_devkitv1_38pin

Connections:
+5V: J1.3, J3.5, U1.38 (VIN)
/MAIN_LED: J2.1a, U1.5 (D2)
/RELAY1: J3.1, U1.34 (D13)
/RELAY1_BTN: J2.2b, U1.7 (D4)
/RELAY1_LED: J2.2a, U1.11 (D18)
/RELAY2: J3.2, U1.32 (D12)
/RELAY2_BTN: J2.3b, U1.18 (D23)
/RELAY2_LED: J2.3a, U1.12 (D19)
/RELAY3: J3.3, U1.31 (D14)
/RELAY3_BTN: J2.4b, U1.4 (D15)
/RELAY3_LED: J2.4a, U1.10 (D5)
/RESET_SW: J4.2, U1.30 (D27)
/SCL: J1.1, U1.17 (D22)
/SDA: J1.2, U1.14 (D21)
Earth: J1.4, J2.1b, J3.4, J3.6, J4.1, U1.13 (GND), U1.19 (GND), U1.33 (GND)

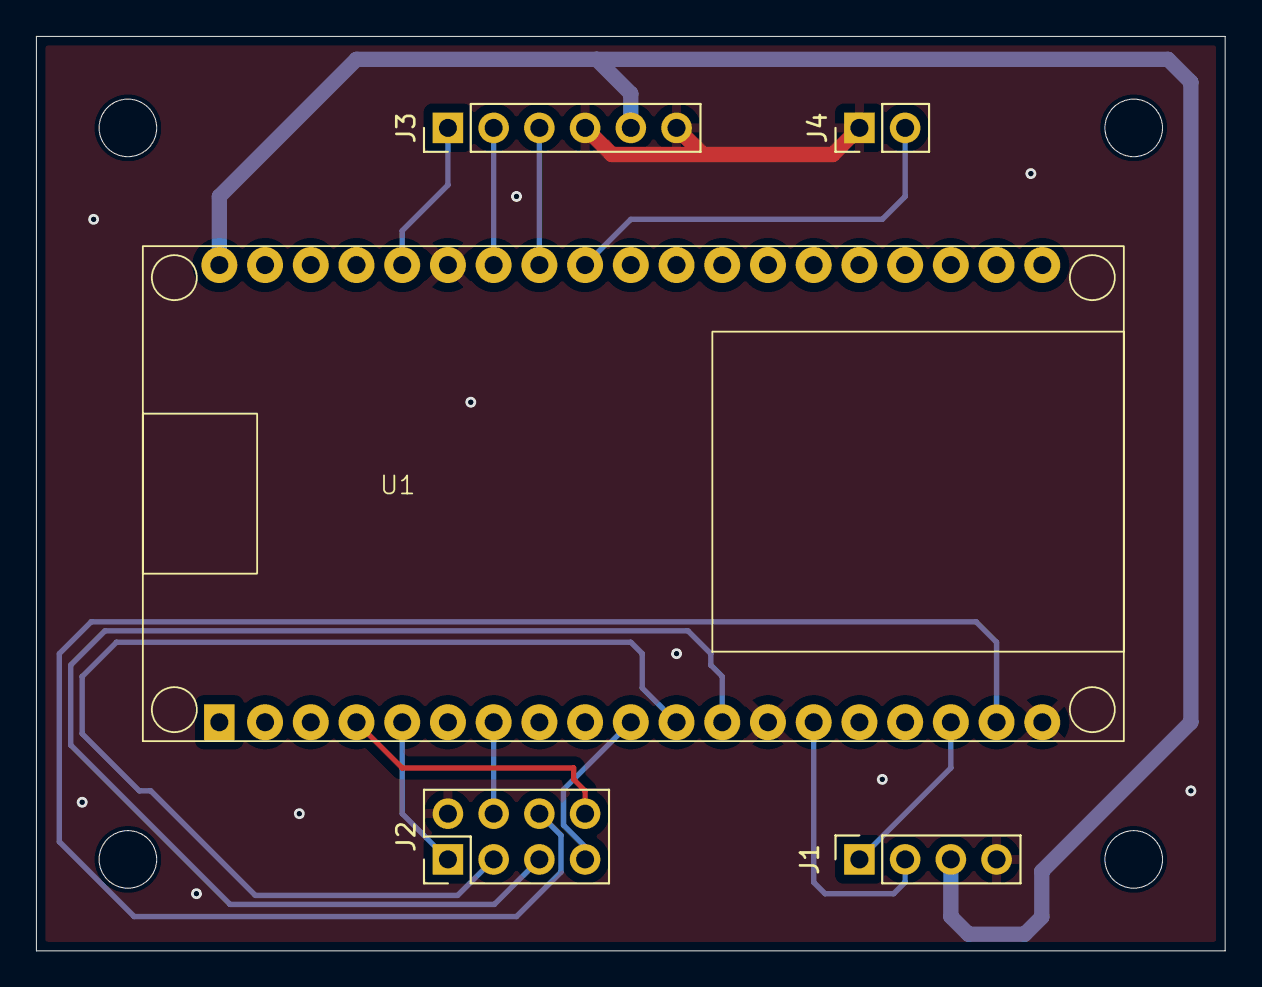
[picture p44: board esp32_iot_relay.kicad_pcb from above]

Board: 2 copper layers, 66.0 x 50.8 mm, 5 parts (0 on the bottom side), 15 nets.

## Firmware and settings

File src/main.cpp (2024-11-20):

#include <Arduino.h>
#include "LED.h"
#include "Button.h"
#include "Relay.h"
#include "RTCNTPlib.h"
#include "EEPROMConfig.h"
#include "Webserver_module.h"

#include "esp_websocket_client.h"

/*
hardware pins
*/ 
const int wifiResetBtnPin = 27;
const int statusLED1Pin = LED_BUILTIN;
const int ledPins[NUMBER_OF_RELAYS] = {18,19,5};
const int buttonPins[NUMBER_OF_RELAYS] = {4,23,15};
const int relayPins[NUMBER_OF_RELAYS] = {13,12,14};
/*
hardware components
*/
LED mainStatusLED(statusLED1Pin);
Button wifiResetBtn(wifiResetBtnPin);
LED statusLEDs[NUMBER_OF_RELAYS] = {LED(ledPins[0]), LED(ledPins[1]), LED(ledPins[2])};
Button buttons[NUMBER_OF_RELAYS] = {Button(buttonPins[0]), Button(buttonPins[1]), Button(buttonPins[2])};
Relay relays[NUMBER_OF_RELAYS] = {Relay(relayPins[0]), Relay(relayPins[1]), Relay(relayPins[2])};

/*
Major modules
*/
RTCNTP rtcntp;
DateTime dtnow;
EEPROMConfig eC;
WebserverModule wsMod;
/*
misc variables
*/
// check timeslots once a second
unsigned long lastTimesTimeSlotsChecked[NUMBER_OF_RELAYS];
// for resetting wifi credentials by long pressing the button
bool resetWiFi = false;
bool resetWiFiBlinkLED = false;
unsigned long resetWiFiTime;
// send the time once a second
unsigned long sendTimeInterval = 1000;
unsigned long lastTimeTimeSent;
// 
int curOperationModes[NUMBER_OF_RELAYS];
/*
If NTP update is called at the same time as the websocket sending data to the ESP32 when there is
no access to the NTP server, such as when the configuration is saved with NTP enabled through a 
WiFi connection that isn't connected to the internet, it will cause the watchdog to reset the ESP32. 
Instead, there is a delay of around 3 seconds so that the 8-second delay caused by the NTP client 
trying to connect to the NTP service simultaneously with the websocket code will not cause the 
watchdog to reset.
*/
bool updateNTPFlag = false;
unsigned long lastTimeUpdateTime;
// relay state
bool newRelayStates[NUMBER_OF_RELAYS];
bool relayStatesForLEDs[NUMBER_OF_RELAYS];
unsigned long lastTimeCountDownSent;

/*
function in the loop to control the relay.
*/
void checkRelaysIfOn() {
  for (int i=0;i<NUMBER_OF_RELAYS;i++) {
    switch (eC.getOperationMode(i)) {
      // manual mode
      case RELAY_MANUAL:
        newRelayStates[i] = eC.getRelayManualSetting(i);
        // Serial.printf("newRelayState=%d\n", newRelayState);
        break;
      // if automatic timer is enabled, check all timeslots if any one of them is on
      // in the current time.
      case RELAY_TIMESLOTS:
        if (millis() - lastTimesTimeSlotsChecked[i] >= 500) {
          lastTimesTimeSlotsChecked[i] = millis();
          dtnow = rtcntp.getRTCTime();
          newRelayStates[i] = eC.checkIfAnyTimeSlotOn(i, dtnow);
        }
        break;
      // countdown timer mode
      case RELAY_COUNTDOWN:
        if (millis() - lastTimesTimeSlotsChecked[i] >= 50) {
          lastTimesTimeSlotsChecked[i] = millis();
          newRelayStates[i] = eC.checkCountdownTimer(i);
        }
        break;
      default:
        newRelayStates[i] = false;
    }
    // only update the relay if the state has changed, minimizing flickering.
    if (newRelayStates[i] != relays[i].readState()) {
      // Serial.printf("before set %d, %d",newRelayState, relay.readState());
      relays[i].set(newRelayStates[i]);
      // Serial.printf("after set %d, %d",newRelayState, relay.readState());
      // update relay state to client
      wsMod.sendCurrentRelayStates(newRelayStates);
    } 
  }
}

/**
 * Flash n times on statusLED(ledIndex)
 * @params
 * LED* led - pointer to LED 
 * int numFlashes - number of flashes
 * bool state - whether the relay is on or off; if the relay is on, the time outside the flashes will be on, but if the
 *    relay is off, the time outside the flashes will be off.
 * 
 * eg. 
 *  for the LED to blink two times, the sequence to do that is below:
 *    0000 10001000 xxxxxxxxxxxxxxxxxxxxxxxxxxxxxxxxxxxxxxxx
 *    Each bit takes 100 ms.
 *    Initial four 0's
 *    one 1 and three 0's for each time to blink
 *    40 bits of the state, where state is the state of the relay.
 * 
 */
void flashOpModeOnLED(LED *led, int numFlashes, bool state=0) {
  led->setLoopUnitDuration(100);
  bool loopseq[MAX_SEQUENCE_LENGTH];
  int i=0;
  for (int j=0;j<4;j++) {
    loopseq[i] = 0;
    i++;
  }
  for (int j=0;j<3;j++) {
    loopseq[i] = j<numFlashes;
    i++;
    for (int k=0;k<3;k++) {
      loopseq[i] = 0;
      i++;
    }
  }
  for (int j=0;j<40;j++) { 
    loopseq[i] = state;
    i++;
  }
  led->setLoopSequence(loopseq, i);
  Serial.println("start loop");
  led->startLoop();
}

// function in loop to set the status LED mode.
void setStatusLEDs() {
  // main LED code
  switch (eC.getMainLEDSetting()) {
    case LED_ON:
      mainStatusLED.on();
      break;
    case LED_BLINK:
      mainStatusLED.blink(3000, 0.08);
      break;
    default:
      mainStatusLED.off();
      break;
  }
  // relay LED code
  for (int i=0;i<NUMBER_OF_RELAYS;i++) {
    switch (eC.getLEDSetting(i))
    {
    case LED_ON:
      statusLEDs[i].on();
      break;
    case LED_BLINK:
      /**
       * if the LED is not looping yet, or 
       * if the operation mode has changed, or
       * if the relay state has changed,
       * restart the LED sequence loop.
      */ 
      if (
        statusLEDs[i].getMode() != LED_LOOP || 
        curOperationModes[i] != eC.getOperationMode(i) ||
        relayStatesForLEDs[i] != relays[i].readState()
      ) {
        curOperationModes[i] = eC.getOperationMode(i);
        relayStatesForLEDs[i] = relays[i].readState();
        // Serial.printf("blinking %d\n", statusLEDs[i].getMode());
        flashOpModeOnLED(&statusLEDs[i], eC.getOperationMode(i), relays[i].readState());
      }
      break;
    default:
      statusLEDs[i].off();
    }
  }
}

/*
callback function to toggle relay state when button is short pressed 
*/
void buttonToggleRelay(int index) {
  bool newState;
  switch (eC.getOperationMode(index)) {
    case 1:
      if (relays[index].readState()) {
        newState = false;
      }
      else {
        newState = true;
      }
      Serial.printf("newstate=%d\n", newState);
      eC.setRelayManualSetting(index, newState);
      Serial.printf("button set relay to %d\n", eC.getRelayManualSetting(index));
      break;
    case 3:
      if (eC.checkCountdownTimer(index)) {
        eC.stopCountdownTimer(index);
      }
      else {
        eC.startCountdownTimer(index);
      }
      break;
    default:
      break;
  }
  eC.saveRelayConfig(index);
}

void buttonToggleMainStatusLED(int i) {
  if (eC.getMainLEDSetting() < 2) {
    eC.setMainLEDSetting(eC.getMainLEDSetting() + 1);
  } else {
    eC.setMainLEDSetting(0);
  }
  eC.saveMainConfig();
  Serial.printf("button set main status LED to %d\n", eC.getMainLEDSetting());
}

/*
callback function to toggle the automatic timer when button is double pressed
*/
void buttonToggleOperationMode(int index) {
  if (eC.getOperationMode(index) < 3) {
    eC.setOperationMode(index, eC.getOperationMode(index)+1);
  } else {
    eC.setOperationMode(index, 0);
  }
  eC.save();
  // Serial.printf("button set operation mode to %d\n", eC.getOperationMode(index));
  statusLEDs[index].startTimer(1000*eC.getOperationMode(index), true);
  statusLEDs[index].blink(1000, 0.5);
  // eC.load();
  Serial.printf("button set operation mode to %d\n", eC.getOperationMode(index));
}

/*
callback function to write default wifi credential values to the EEPROM when 
the button is long pressed.
*/
void buttonResetWiFi(int i) {
  resetWiFi = true;
  resetWiFiBlinkLED = true;
  resetWiFiTime = millis();
  Serial.println("button trigger reset wifi");
}

/*
Loop function to reset the wifi credential values when requested.
*/
void checkToResetWiFi() {
  if (resetWiFiBlinkLED) {
    mainStatusLED.startTimer(2000, true);
    mainStatusLED.blink(800, 0.5);
    resetWiFiBlinkLED = false;
  }

  if (resetWiFi && millis() - resetWiFiTime > 2100) {
    Serial.println("resetting wifi...");
    JsonDocument resetWiFi;
    resetWiFi["ssid"] = "default-SSID";
    resetWiFi["pass"] = "password";
    resetWiFi["ipIndex"] = 2;
    resetWiFi["port"] = 7777;
    wsMod.receiveConnection(resetWiFi);
  }
}

/*
callback function to update NTP time when it is enabled.
*/
void updateTime() {
  Serial.print("updateTIme: ");
  Serial.println(eC.getNTPEnabled());
  if (eC.getNTPEnabled()) {
    updateNTPFlag = true;
    lastTimeUpdateTime = millis();
    Serial.println("updateTime");
  }
}

/*
function in loop to update NTP time 3 seconds after the websocket has completed
its current operation. Read the comments at the top of the file. */
void updateTimeInLoop() {
  if (updateNTPFlag && millis() - lastTimeUpdateTime > 3000) {
    updateNTPFlag = false;
    rtcntp.setGMTOffset(eC.getGMTOffset());
    rtcntp.updateRTCWithNTP();
    dtnow = rtcntp.getRTCTime();
    Serial.println("updateTimeInLoop");
  }
}

/*
function in loop to send time once a second to the client.
*/
void sendTime() {
  if (millis() - lastTimeTimeSent > sendTimeInterval) {
    lastTimeTimeSent = millis();
    wsMod.sendDateTime();
    rtcntp.printTime();
  }
}

void sendCountDown() {
  bool anyCountDown = false;
  for (int i=0;i<NUMBER_OF_RELAYS;i++) {
    if (eC.getOperationMode(i) == RELAY_COUNTDOWN) anyCountDown = true;
  }
  // eC.checkCountdownTimer
  if (anyCountDown && millis() - lastTimeCountDownSent > 1000) {
    lastTimeCountDownSent = millis();
    wsMod.sendCountDownState();
    Serial.println("countdown sent");
  }
}

void setup() {
  Serial.begin(115200);
  // littleFS 
  if (!LittleFS.begin()) {
    Serial.println("An error occured while mounting LittleFS.");
  }

  mainStatusLED.begin();
  wifiResetBtn.begin();
  wifiResetBtn.setIndex(4);
  wifiResetBtn.setShortPressFunc(buttonToggleMainStatusLED);
  wifiResetBtn.setLongPressFunc(buttonResetWiFi);
  for (int i=0;i<NUMBER_OF_RELAYS;i++) {
    // init status LED
    statusLEDs[i].begin();
    // init button
    buttons[i].setIndex(i);
    buttons[i].begin();
    buttons[i].setShortPressFunc(buttonToggleRelay);
    buttons[i].setDoublePressFunc(buttonToggleOperationMode);
    // button.setLongPressFunc();
    // init relay
    relays[i].begin();
    relays[i].set(LOW); // turn off relay
  }

  // init eeprom config
  eC.begin();
  eC.load();

  // init wsmod
  // scan wifi
  wsMod.scanWiFi();
  wsMod.begin(&eC, &rtcntp, relays);
  // set websocket callback functions
  wsMod.setSendConnectionCallback();
  wsMod.setSendDateTimeCallback();
  wsMod.setSendRelayStateCallback();
  wsMod.setSendConfigCallback();
  wsMod.setReceiveConnectionCallback();
  wsMod.setReceiveDateTimeCallback(updateTime);
  wsMod.setReceiveRelayStateCallback();
  wsMod.setReceiveConfigCallback(updateTime);
  wsMod.connect();

  // init rtcntp
  rtcntp.begin();
  // update RTC with NTP only if NTP is enabled
  updateTime();
  dtnow = rtcntp.getRTCTime();

  // initialize ec timeslots
  eC.load(dtnow);

  eC.print();
  rtcntp.printTime();
}

void loop() {
  mainStatusLED.loop();
  wifiResetBtn.loop();
  // start concurrent loops
  for (int i=0;i<NUMBER_OF_RELAYS;i++) {
    statusLEDs[i].loop();
  }
  for (int i=0;i<NUMBER_OF_RELAYS;i++) {
    buttons[i].loop();
  }
  wsMod.cleanupClients();
  wsMod.checkWiFiStatusLoop();

  checkRelaysIfOn();
  setStatusLEDs();
  checkToResetWiFi();
  sendTime();

  updateTimeInLoop();
  sendCountDown();
}

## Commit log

2024-09-03 button control for toggling timer enable and relay state
2024-09-03 button long press now resets wifi connection to factory default
    [main.cpp]
2024-09-05 in updateTime, setGMTOffset was moved before updateRTCWithNTP to fix the bug of the GMT offset not being applied properly.
    [main.cpp]
2024-09-21 working relay status realtime update on browser
2024-09-25 added some more code to display values from the ESP32 to the browser Fixed bug in sending current relay states from ESP32 to browser
    [main.cpp]
2024-09-26 added bugfix for relay state resetting to false in function call checkRelayIfOn
    [main.cpp]
2024-09-27 made changes to wifi.js to use a template for wifi hotspot table rows instead of creating a new row manually for each wifi hotspot Used window.location.port to get port in javascript Fixed bug with p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
    [main.cpp]
2024-09-30 resolved watchdog reset with ntp websockets with no internet Tidied up and put comments in main.cpp
    [main.cpp]
2024-10-01 fixed bug with automatic timer when a timeslot has startTime before 12AM, endTime after 12AM, and now after 12AM.
2024-10-03 removed interrupt from setFullOnOffTimes
2024-10-08 working countdown timer, toggle, start, and stop with button
2024-10-09 countdown timer feature now working with webpage GUI
2024-10-10 revised EEPROMConfig to have multiple relay configs
2024-10-10 webserver module multiple relays WIP
2024-10-12 working button toggles, next is to revise the javascript so that the websocket methods can be tested.
2024-10-12 updated html for multiple relays
2024-10-13 added multiple relay statuses to html
2024-10-14 multiple relay states working
2024-10-15 fixed bug with relay config not saving uploaded fs to esp32 goal is to make minor UI fixes for ease of use
2024-10-16 fixed the annoying issue with the EEPROM not committing (changed all the shorts into ints) added wifi reset button and main status LED cuz moar LEDs cool
2024-10-18 improved status LED blinking behavior
2024-10-18 working v3 yay website save buttons are now disabled until any config is modified. status LEDs now flash out the operation mode of that relay.
2024-10-18 wifi password field set timeslot inputs event listener to enable relay config save button
2024-10-21 pcb files
    [esp32_iot_relay.kicad_pcb, esp32_iot_relay.kicad_sch, led_button_board.sch.kicad_sch]
2024-10-22 symbols for ESP32 boards
    [esp32_iot_relay.kicad_pcb]
2024-10-22 completed schematic and passed ERC, basic footprint arrangements done.
    [esp32_iot_relay.kicad_pcb, esp32_iot_relay.kicad_sch, led_button_board.sch.kicad_sch]
2024-10-23 minor bug with relay start stop button on webpage
2024-10-23 completed main PCB currently working on leds_buttons_pcb
    [esp32_iot_relay.kicad_pcb, esp32_iot_relay.kicad_sch, esp32_iot_relay_led_button_board.kicad_pcb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]
2024-10-24 completed led and button board
    [esp32_iot_relay_led_button_board.kicad_pcb, esp32_iot_relay_led_button_board.kicad_sch]
2024-10-24 completed reset button PCB
    [esp32_iot_relay_reset_button.kicad_pcb]
2024-11-03 updated PCB designs to have standard breadboard spacing used mil spacing
    [esp32_iot_relay.kicad_pcb, esp32_iot_relay_led_button_board.kicad_pcb, esp32_iot_relay_reset_button.kicad_pcb]
2024-11-20 fix bug with the countdown timer start/stop button every time the relay selector is changed
2024-11-20 changed LED behavior to: Off: LED is totally off On: LED is totally on Blinking: LED blinks the current operation mode periodically, but is mostly off when the relay is off and mostly on when the rel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
2024-11-20 add a time remaining countdown beside each relay which appears when countdown mode and relay is activated It works well in softAP mode but lags in STA mode, maybe because of the latency of the mcu to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
